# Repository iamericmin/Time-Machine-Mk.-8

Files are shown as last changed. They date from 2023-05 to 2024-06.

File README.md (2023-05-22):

# Time Machine Mk. 8
Home of the Time Machine Mk. 8, a digital watch inspired by F1 and Neon Genesis Evangelion.

# Repo Map
TM8-firmware:
<<<<<<< HEAD
	- scratchpad: Arduino sketches for quick testing
	- TM8: PlatfomIO project directory.

TM8-hardware:
	- root: Contains current TM8 production files and top/bottom PNG renders
	- Prototypes: previous versions of TM8. Current versions in root directory.
	- Technical Drawings: PDFs of TM8 exported from Eagle
	- Cutting Board: old TM8 versions that were tossed away
	- dock: TM8 dock design files
	- Side projects: smaller side projects to go along with TM8.
=======
  1. scratchpad: Arduino sketches for quick testing
  2. TM8: PlatfomIO project directory.

TM8-hardware:
  1. root: Contains current TM8 production files and top/bottom PNG renders
  2. Prototypes: previous versions of TM8. Current versions in root directory.
  3. Technical Drawings: PDFs of TM8 exported from Eagle
  4. Cutting Board: old TM8 versions that were tossed away
  5. dock: TM8 dock design files
  6. Side projects: smaller side projects to go along with TM8.
>>>>>>> 88637fd49bccefb3e3033934de54475b4d8ace5f

Documentation directory will be created soon!

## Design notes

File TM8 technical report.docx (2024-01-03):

TIME MACHINE MK. 8

Technical Report

Chief Technical Officer Eric Min

SPECS:

  1. CPU: ATSAMD21G18A-AU ARM CORTEX M0+ @ 48MHz
  2. DIMENSIONS: 41.91mm x 41.91mm x 8.6mm
  3. I/O: 4 momentary switches, central rotary knob, twin LCD displays, 5 auxiliary front LEDs, twin RGB backlights, twin floodlights, piezo buzzer, USB port
  4. COLORWAY: Electroless nickel-immersion gold on red soldermask, “Thunder and Lightning”
  5. POWER: LIR2032 40mAh Lithium Polymer coin cell battery w/ charging over micro-USB
  6. SENSORS: BME680 Temperature/Humidity/Barometer/Altitude sensor, LIS3DH 3-axis accelerometer, MAX17048 battery fuel gauge
  7. FIRMWARE: written in C/C++ with PlatformIO’s Arduino Atmel-SAM framework

DESIGN

Overall design: Chief Design Engineer Eric Min

Designing the Time Machine Mk. 8 to be both beautiful and practical required very deep thinking. Our team had to straddle a fine line between striking design and everyday useability. Finding the convergence point of those two crucial characteristics was extremely difficult, but our design team fulfilled every goal we initially set out to do, and some more. The Time Machine Mk. 8 retains the instantly recognizable silhouette of its predecessors, but brings forth a whole slew of incredibly advanced features, all in a smaller package.

The Time Machine Mk. 8 is a huge step forward in terms of technological prowess and design goals. While previous generation Time Machines were very simple watches cobbled together without much thought, TM8 is our first product made with focus on a singular goal: maximum performance and style at the lowest possible power consumption. We wanted to retain the iconic design language of our previous Time Machines, while still incorporating the numerous new features of our new model. This proved much harder than we initially thought, but at the end, it couldn’t have turned out any better.

Ever since the Mk. 2, the Time Machines’ muscular and angular lines have been an integral part of its design language. With the Mk. 8, we reprofiled the “fender flares” to be better proportioned with the rest of the chassis, as well as mimic the look of the muscular bulged fenders of classic 80’s cars, such as the Fiat 131 Abarth or the Lamborghini Countach. More importantly, while the fender flares were simply a design element in previous time machines, it actually serves a functional purpose in the Mk. 8 since it provides valuable PCB area for the numerous new functions we added to the watch. Without them, we wouldn’t have been able to fit in all the features we had planned.

Ergonomics & Front Fascia design: Systems Designer Eric Min

The front fascia is a radical departure from the usual two-digit, three-button layout familiar in previous generations. Our team decided two digits was not going to be enough for TM8, since with its new telemetry sensors, the watch would have to relay more information than just time. It took a painfully long time to look for and decide on the right display. Near the end, our team narrowed it down to a four digit, seven segment display as it fit nicely with our retro-futuristic design. While an OLED display was significantly cheaper and had better graphics, the design team concluded it would look awkward with the rest of the watch, and was therefore sacked. We trusted our software team to squeeze the most out of the LCD’s limitations. After all, working with and around limitations is what we do best. Furthermore, not only would the LCD provide significantly lower power consumption, the design team also fell in love with the fact that when two of those LCDs were put side by side, it resembled something like a Formula 1 steering wheel. Which brings us to the buttons…

While Min Works solely works in the electrical domain, we have always been fascinated by all things mechanical, automobiles being one of them. One day, we came up with the novel idea of making the Time Machine Mk. 8’s front fascia resemble an F1 steering wheel. Skeptical at first, our design team quickly landed on a design that made excellent use of available space without compromising usability and design. The final design has a central rotary “cooker” knob, flanked by two tactile momentary switches on each side, with twin LCDs on top to make an 8-digit display. The five auxiliary LEDs were carried over directly from previous generations, placed in parallel with the fender flares like the Mk. 4. The result is an extremely unique design that satisfies all our target design goals without compromising practicality.

The central cooker knob provides a new method of user input, not too different from the digital crown in an Apple Watch. The 16-step cooker knob provides a satisfying click with each actuation, and we think the engraved hexadecimal codes provide extra design flair to the watch. Unlike a conventional rotary switch, the one on TM8 outputs in 4-bit parallel BCD, meaning our software doesn’t have to track and store actuator position, making firmware development significantly easier.

The flanked buttons were angled to provide a more aggressive look, but also to provide enough distance apart so that a finger could feel and press the buttons without the user having to look at the watch. This would be useful in situations such as lap timing, when the user would have the watch strapped to a steering wheel. Being able to “touch-type” would be crucial during such instances.

Livery & Aesthetics: Graphics Designer Eric Min

The design team was at first a bit afraid that our design goals of incorporating twin LCDs and a cluster of buttons and switches would limit PCB space for a livery, but it turned out we just weren’t being creative enough. Our livery design took more development time than we would like to admit, but the end results are simply phenomenal. Our team dubbed the TM8’s design, “Thunder and Lighting.”

On the left, we have exposed copper artwork of a thunderbolt, painstakingly designed to fit in well with the overarching aesthetic of the watch. It took us quite a long time to land on a design that was visually striking but not overly busy.

On the right, our circuit design engineers worked in tandem with the design team and took some liberty to route copper traces that would work both functionally and aesthetically. When PCB routing was finalized, the design team overlayed select copper traces with white silkscreen to make a “lightning bolt” of signals. Like “thunder”, “lightning” also took quite a bit of time in coming up with the overall design, selecting which traces to paint white, and which to keep red. Accompanying “lightning” is a stylized Min Works logo, along with a small “TM-008 PROTOTYPE” script nestled into the upper-right corner, both in exposed copper.

Often, the design team was split into opinions of how our livery looked; some thought it was too busy, while others thought it was a bit subtle. Much debate and discussion went on between these parties, but we eventually reached a nice middle ground that gave just enough visual pop without being too loud.

For the lugs, we took inspiration from Unit 02 from Neon Genesis Evangelion. With Red being our representative color, we found Eva Unit 02 to be the perfect design inspiration, which we took in the form of exposed copper scripts on the lugs. On the front, they designate the model number and on the back, we have lyrics for Frank Sinatra’s Fly Me to the Moon, a tribute to Min Works’s founder Jihong Min, who is an Evangelion afficionado. Additionally, the lugs were reduced from 22mm to 18mm, and the lug hole corners were chamfered in for better structural rigidity, as acute angles are more prone to mechanical stress than obtuse angles.

HARDWARE DESIGN

Overall hardware: Chief Technical Officer Eric Min

Designing any embedded system is no easy task, but it was especially hard for Time Machine Mk. 8, where our primary goal was to cram as many features as possible into the smallest amount of space while using the least amount of power. Before anything else, our hardware design team came up with a list of hard rules that would set the limitations for designing Time Machine Mk. 8:

1. The watch must be smaller than any previous Time Machine, without any compromise on previous features.
2. PCB should be 2 layers with minimum trace width at 8 mils, and minimum via diameter at 0.3mm
3. The battery must be rechargeable, and charging should be fully contained on the PCB without the need for any external circuitry.
4. The battery must be a 40mAh LIR2032 Li-Po coin cell, held directly onto the PCB for minimum thickness.
5. The microcontroller must deliver high performance with low power, with an RTC, native USB, and at least two I2C buses required.
6. The watch should do more than simply measure and tell time.
7. Only the LCDs, LEDs, and buttons are allowed on the front side. All other components should be away from view at the back, or under the LCD glass.

Our engineers followed this set of rules throughout the entire design process, and while we were temped to break some of them, especially rules 1 and 2, we eventually developed TM8 as a fully self-contained package satisfying all our design goals.

Microcontroller: Embedded Systems Engineer Eric Min

With so many incredible microcontrollers available for dirt cheap on today’s market, it was pretty tough deciding on a micro to power our latest watch. Our team was focused primarily on ultra low power performance, and we flipped through hundreds of datasheets and manufacturer reference pages while narrowing down our choices. We decided early on to choose a 32-bit processor, as the current crop of ARM Cortex microcontrollers offered excellent computational performance while also killing the low-power game. Our requirement of a real-time clock and two I2C buses were also nowhere to be found on any 8-bit micro. After some research, our team whittled our list down to five choices: Espressif’s ESP32, Nordic’s NRF52832, the Raspberry Pi Foundation’s RP2040, Microchip’s ATSAMD21G18, or Silab’s EFM32 Zero Gecko, in descending order of performance.

We finally decided on the ATSAMD21G18 since we believed it gave the best performance and peripheral set with uncompromising low-power consumption, along with an incredible community of fellow engineers to rely on with any technical issues. The chip’s high popularity also meant we had no shortage of excellent reference designs to follow, such as Adafruit’s Feather M0 or Sparkfun’s 9DoF Razor IMU. We especially found the SAMD21’s SERCOMs extra appealing as it gave us incredible flexibility when routing our PCB. We didn’t have to worry as much about parts placement as we could simply assign I2C buses to pins best placed for the job. While the ESP32 and NRF52832’s wireless peripherals were pretty enticing, the team concluded that high power consumption during moments of wireless activity defeated the watch’s purpose. With a 40mAh battery, any sort of wireless radio would drain the battery pretty fast. Plus, their lack of native USB meant an automatic no from the get-go.

The SAMD21’s real-time clock (RTC) was also incredibly handy, as it allowed us to keep track of time without any CPU overhead and minimal power consumption.

Sensors: Telemetry Engineer Eric Min

As stated in the requirements above, we wanted Time Machine Mk. 8 to be more than just a time-telling device. Unlike previous versions, which didn’t do more than tell the time, the Mk. 8 is a genuine precision tool capable of measuring, recording, and analyzing various telemetry data. With so many incredible sensors available off-the-shelf, we took our time deciding which sensors to use, before landing on three: Analog Devices’ MAX17048 fuel gauge, Bosch Sensortec’s BME680 environmental sensor, and ST Micro’s LIS3DH 3-axis accelerometer. The first one was a no-brainer: while we considered implementing a rudimentary battery gauge using an ADC pin, we figured an external sensor’s higher accuracy and simple I2C communication was worth it. The BME680 offered a thermometer, humidity sensor, and barometer, while still boasting incredibly low power consumption, giving us an excellent low-power, high-performance sensor package. While we wanted to use Invensense’s ICM20948 9-DoF IMU, we couldn’t find any PCB space to incorporate the sensor’s required 1.8v power regulation circuitry. We figured the next best option would be a 3-axis accelerometer, and the LIS3DH offers great performance for low power. These sensors, coupled with the lean and fast ATSAMD21G18 processor, allow for incredibly fast telemetry acquisition and computation in real time.

Battery: Low-Power design engineer Eric Min

Pretty much everything in TM8’s design process revolved around the battery. We decided early on to incorporate a coin cell battery directly on the watch, just like previous Time Machines, to make it as thin as possible. While this would hurt its battery life, slick aesthetics was also one of our main design goals, and we believed in our low-power design team to work their magic to squeeze the most battery life out of the SAMD21 as possible. We decided to go for a rechargeable battery to mitigate this loss. Luckily, there was an off-the-shelf rechargeable alternative to CR2032 cells, the LIR2032. Being only 40mAh, it’s less than five times smaller than a CR2032, but its familiar 20mm diameter, 3.2mm thickness footprint made PCB design much easier than it would have been with other conventional lithium-polymer batteries.

With no prior experience with rechargeable batteries, we were taking a huge risk here with TM8. We studied numerous reference designs on the internet, and found some solid ones with good documentation that allowed us to make our own reliable power supply circuit. Using a 3.3v LDO voltage regulator, a Li-Po battery charger IC, and a P-channel MOSFET, our team created a rock-solid power supply with seamless switching between the battery and external USB power. Coupled with the MAX17048 fuel gauge IC, TM8 is well optimized for low-power operation.

PCB Design: PCB designer Eric Min

With the battery taking over a quarter of available space on the back of the watch, PCB space was incredibly tight, and our team worked for months optimizing the routing to find space. We are happy to report we’ve successfully implemented all our design goals within our target spec: 2 layers with traces no thicker than 8 mils. Our target spec was chosen so to minimize cost, as any tighter tolerances would’ve dramatically increased manufacturing costs. At one point we even had an IR receiver on the watch, but we removed it after a team meeting concluded it was too niche to be a legitimately useful feature. Instead, we replaced it with test pads for easier hardware debugging, should the need arise. Even without an IR receiver, TM8 is still the most complex, dense circuit we’ve ever designed. In fact, you can see components forming an arc right above where the battery sits, giving it just enough clearance to fit on the watch. Every nook and cranny was utilized, and we left no space on the watch unoccupied.

To route such a dense PCB, our team used 0402 size parts for the first time ever and reduced via size to 0.3mm. We also used SMD packages such as LGA and QFN for the first time. Using such footprints dramatically increased available board space. Time Machine Mk. 8 gave us numerous opportunities to try out new technologies, giving us valuable experience to build upon them in future projects.

While the front side wasn’t as

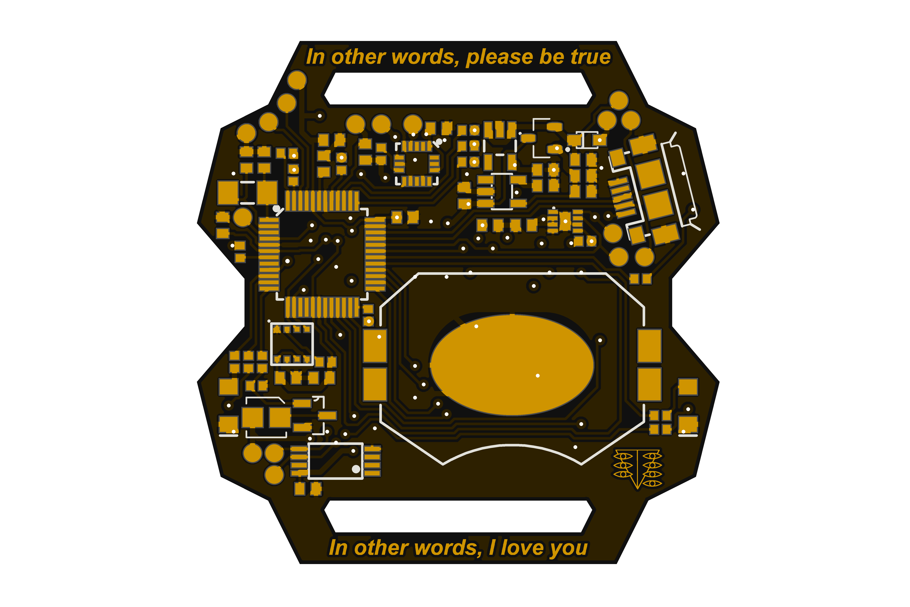
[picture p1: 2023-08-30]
TM8-hardware/tm8_bottom.png

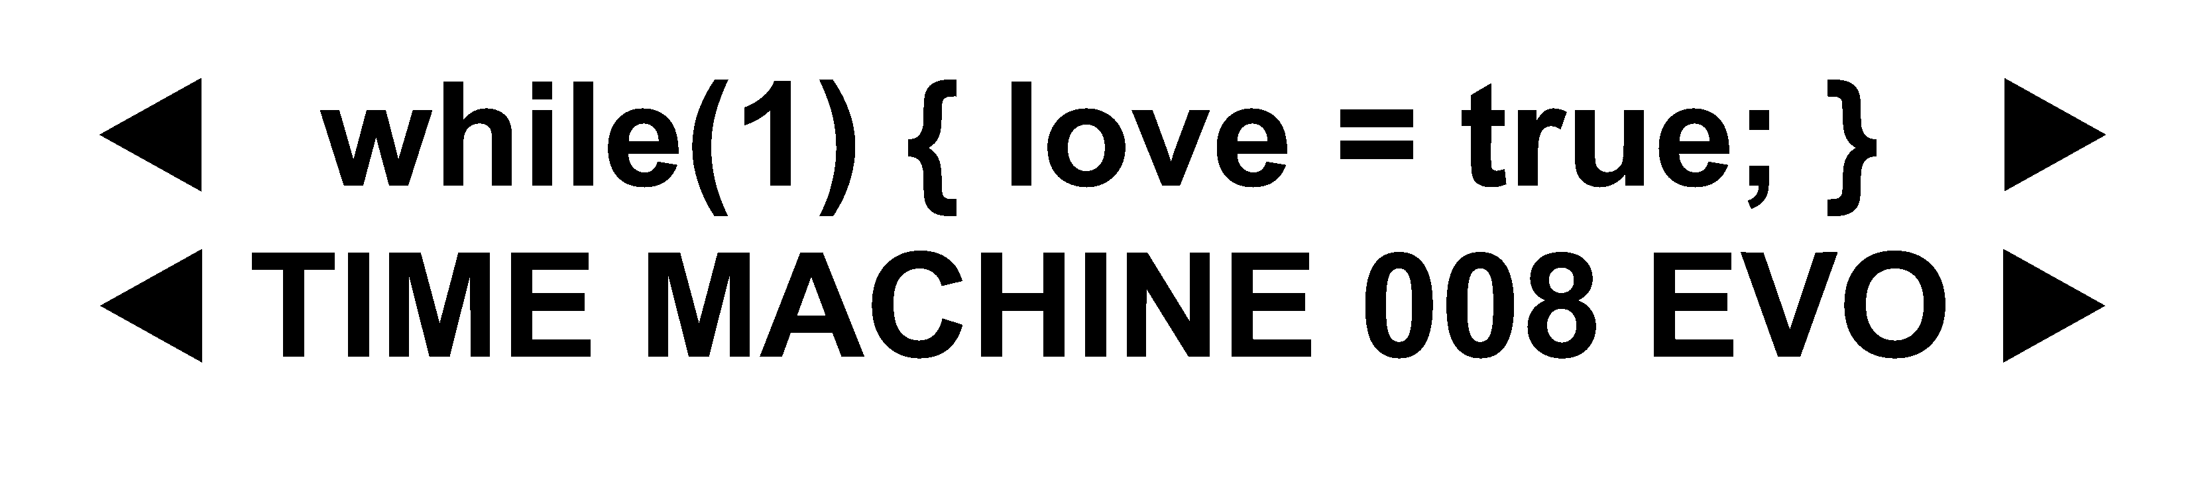
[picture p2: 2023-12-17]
TM8-hardware/resources/lug text.bmp

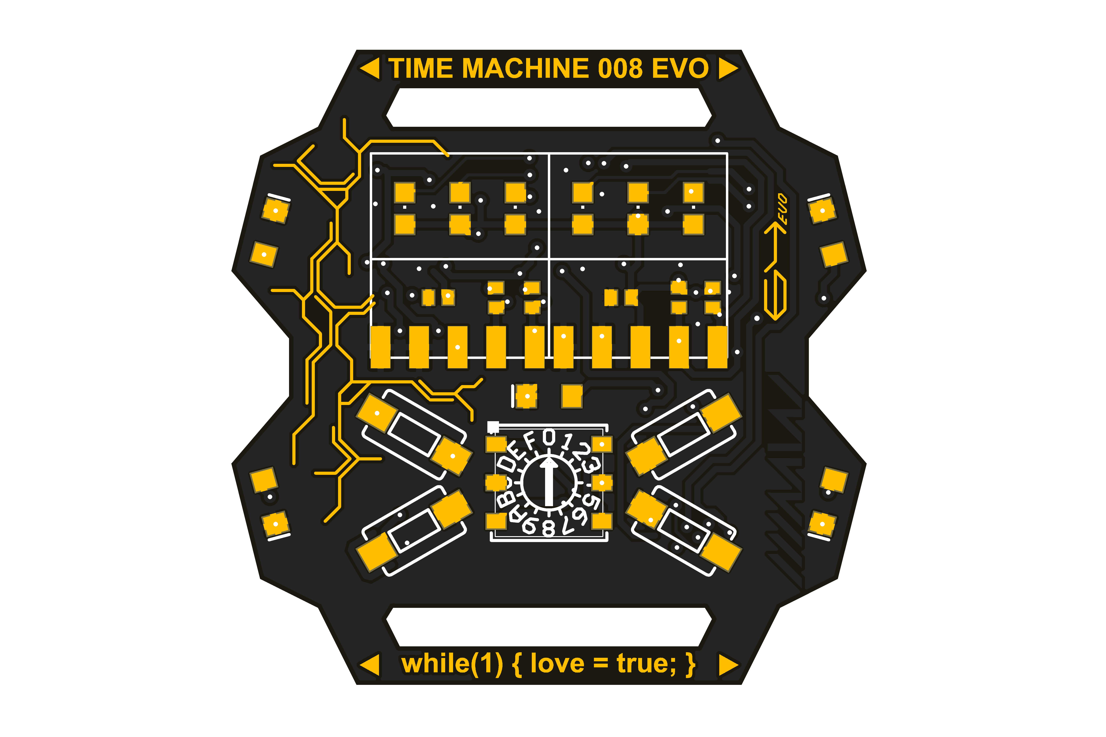
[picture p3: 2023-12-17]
TM8-hardware/TM8 Evo Dad.png

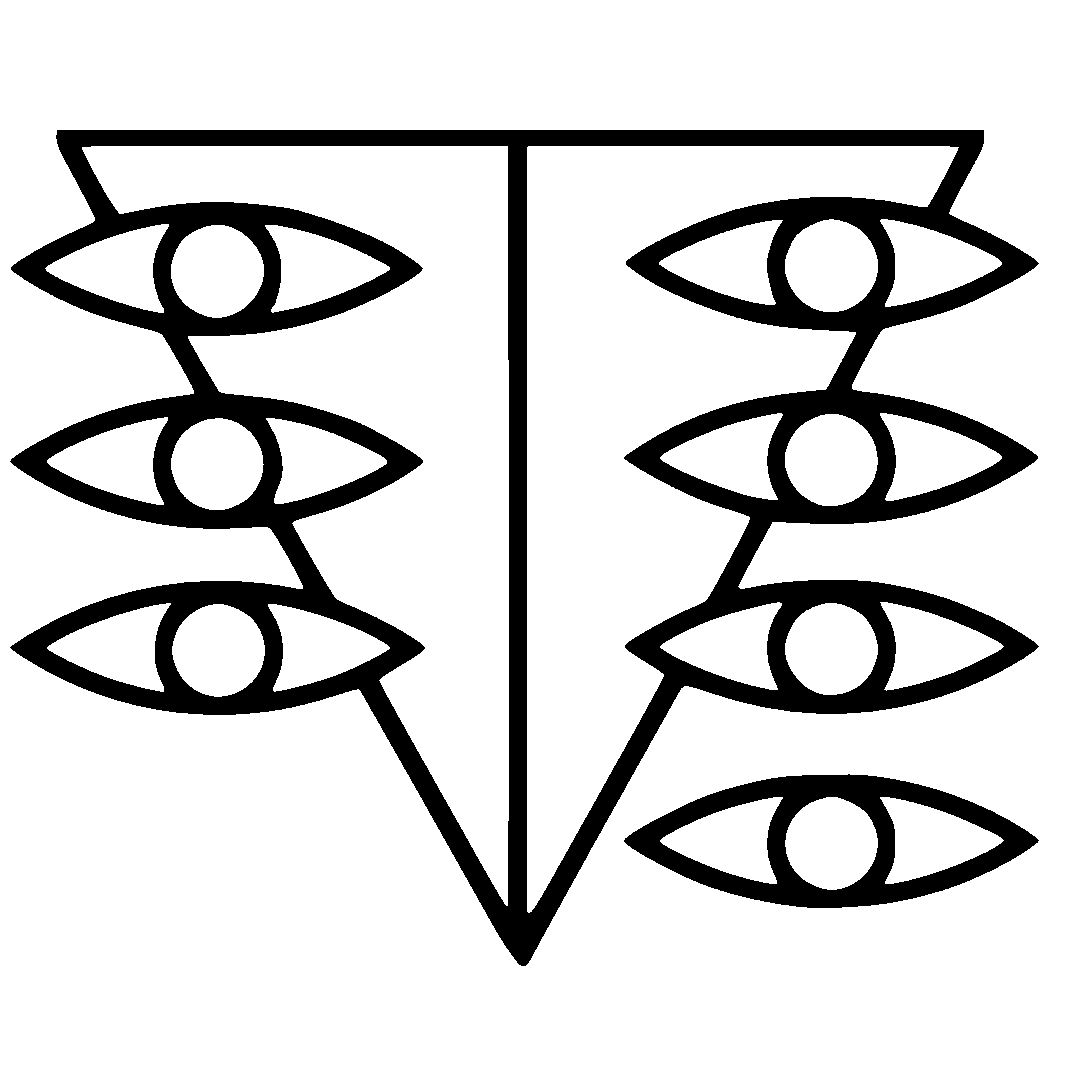
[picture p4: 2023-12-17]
TM8-hardware/resources/seele.bmp

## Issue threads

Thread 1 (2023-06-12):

Idea

SpeedGP, 2023-06-12:
Hey, sorry, I'm awful with Github stuff, but I was curious if you'd be interested in some sort of trade. I have a laser cutter and would like to make a protective plate or shell for this watch. Would you consider sending me one (I'm happy to solder my own if you wanted to send unsoldered components) and I could make a few different shell designs and send them to you.

Awesome work, keep it up!

James

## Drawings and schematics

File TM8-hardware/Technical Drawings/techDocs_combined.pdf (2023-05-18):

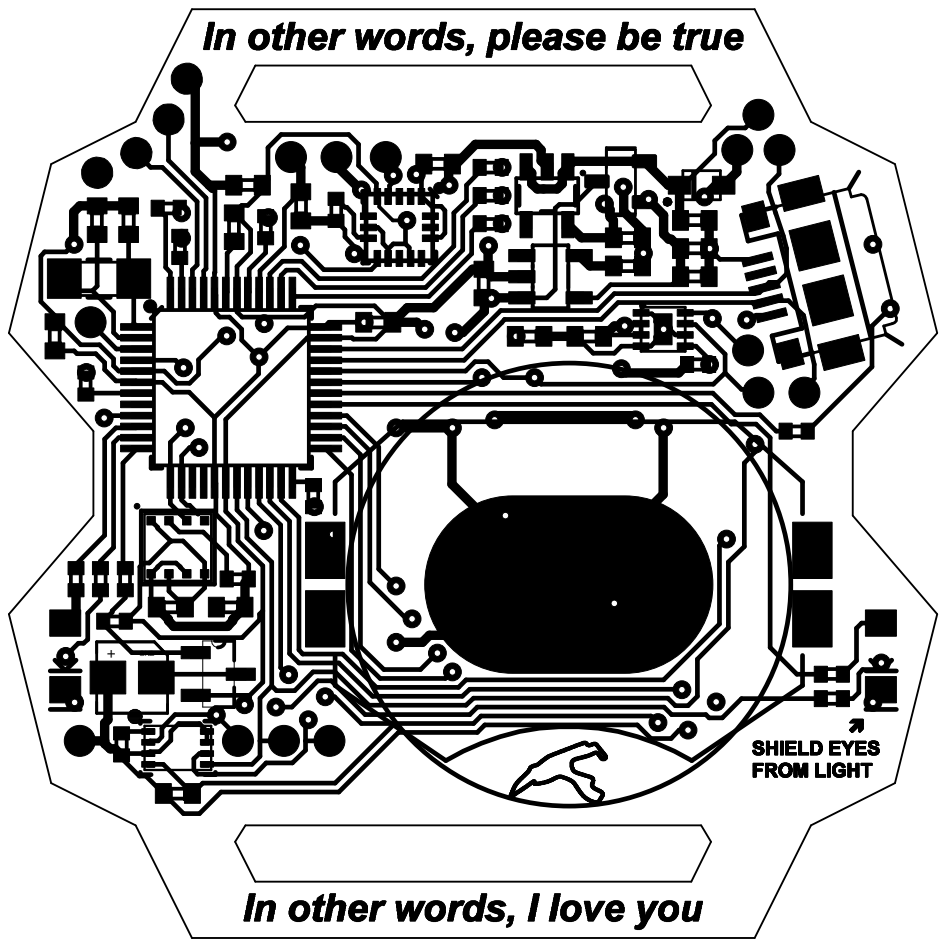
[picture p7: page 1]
GND

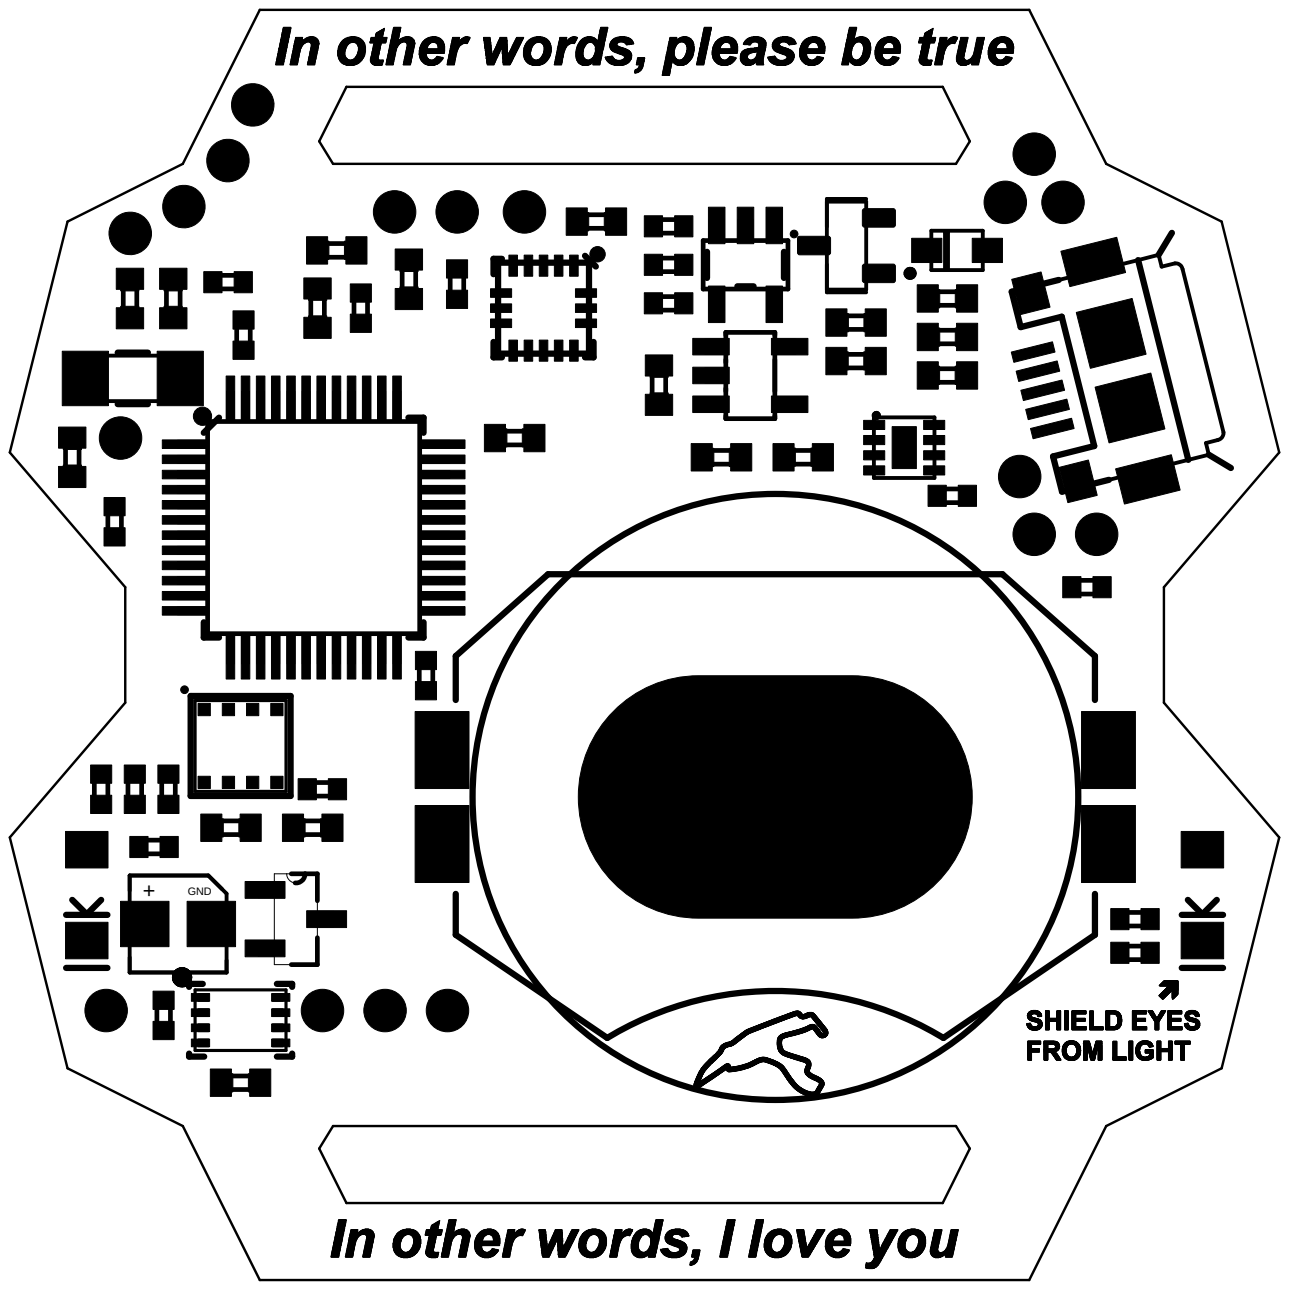
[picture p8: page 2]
GND

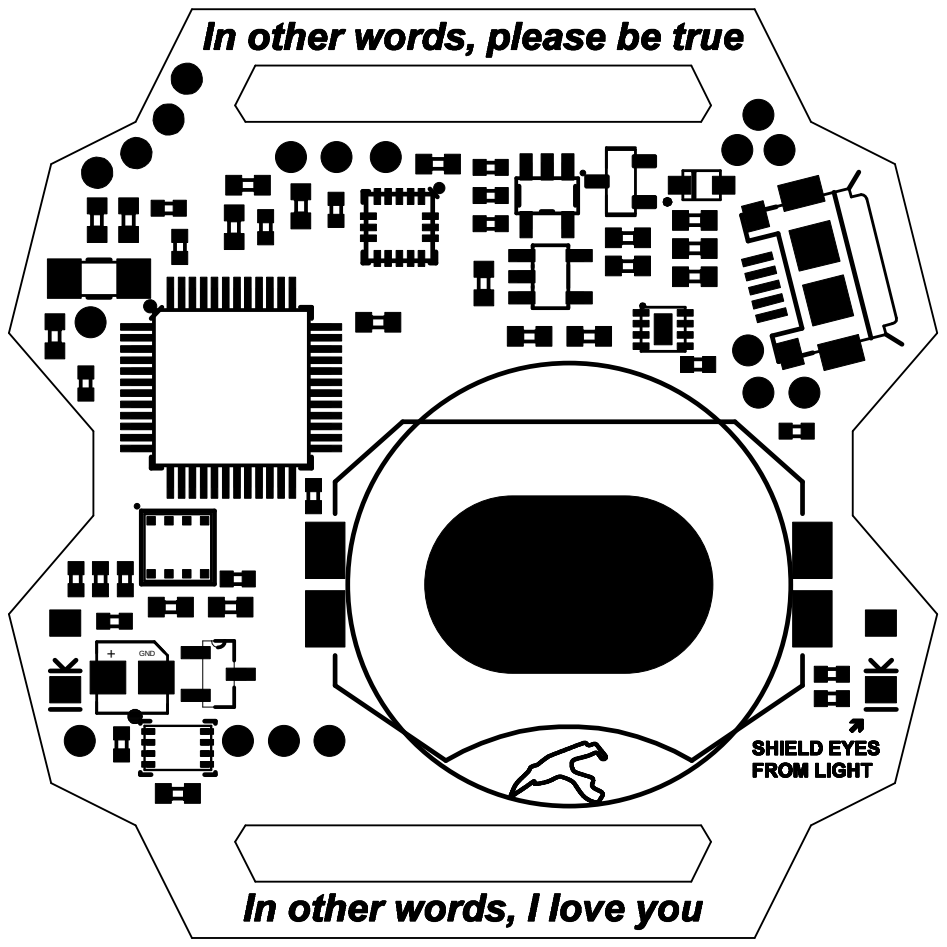
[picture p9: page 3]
GND

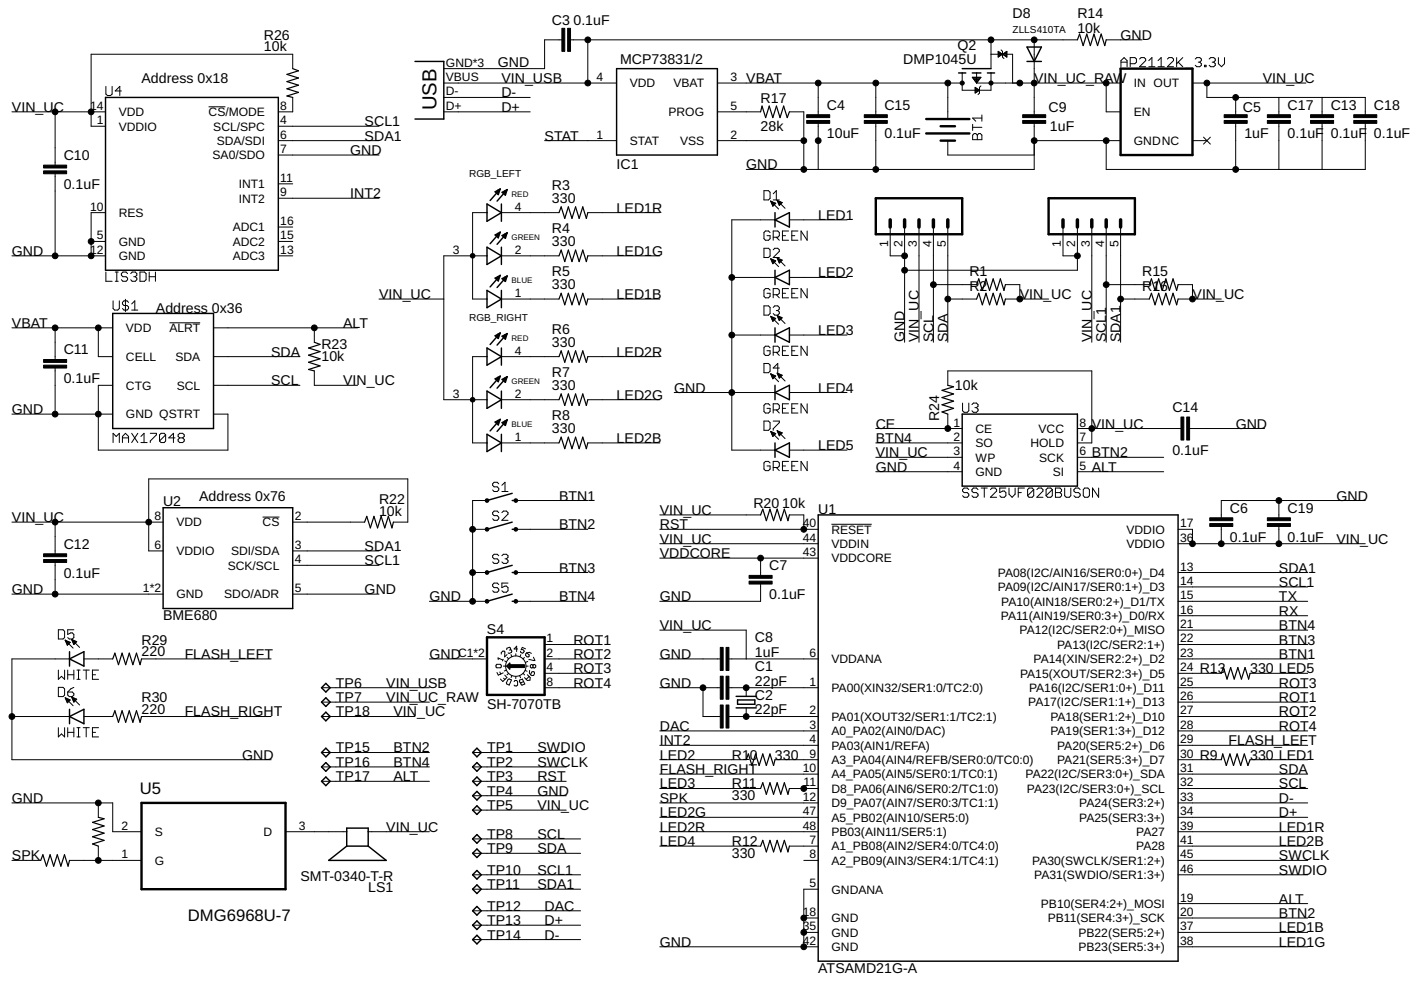
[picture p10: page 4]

GND QSTRT SCL SDA

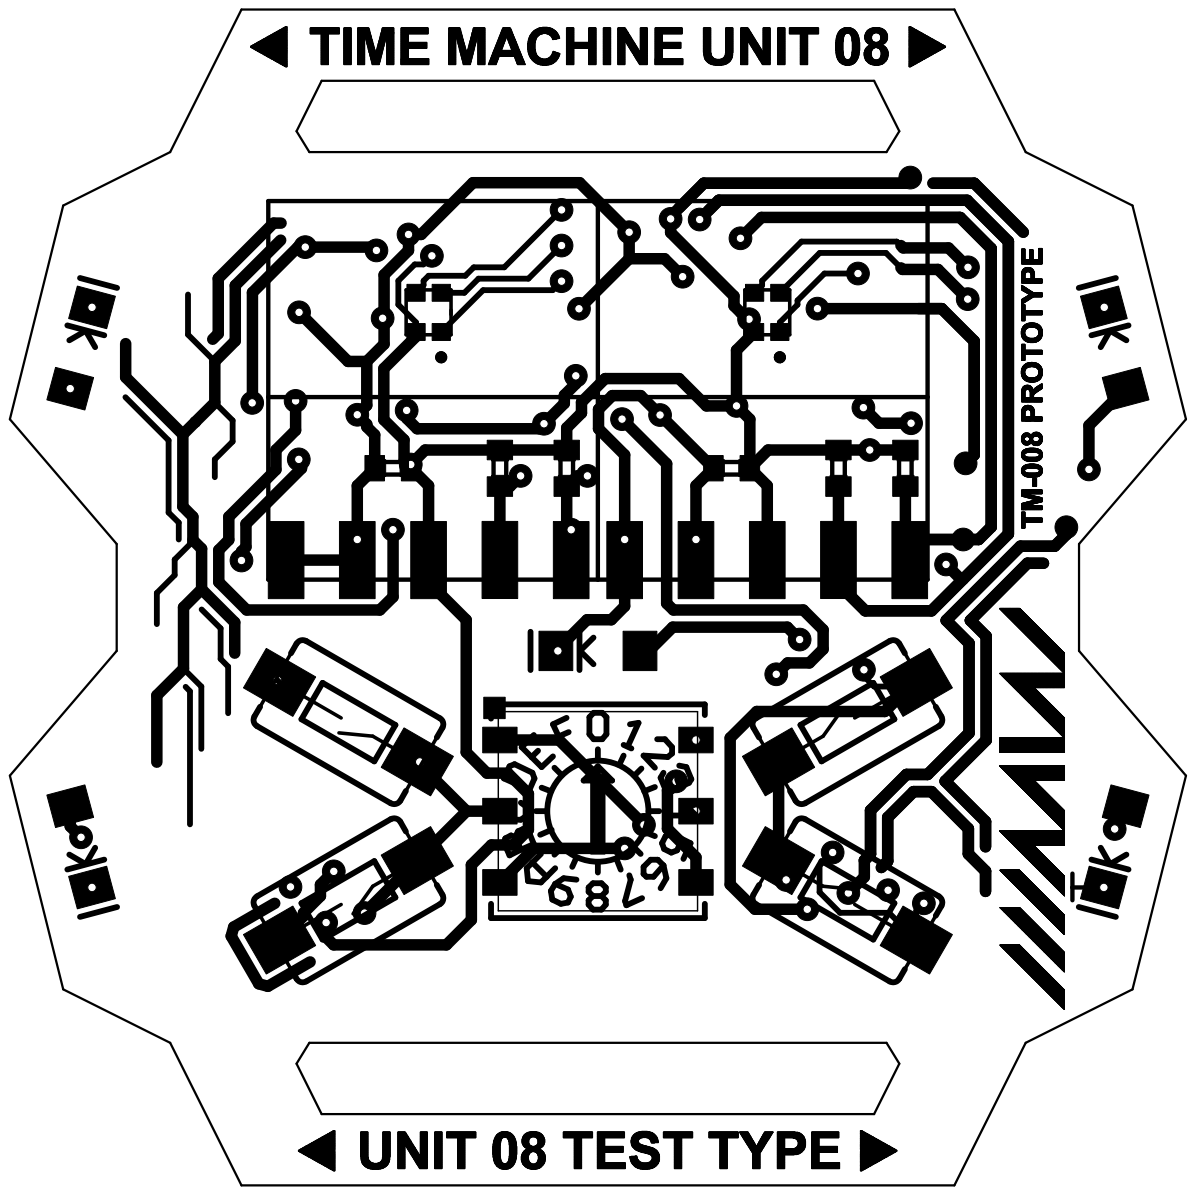
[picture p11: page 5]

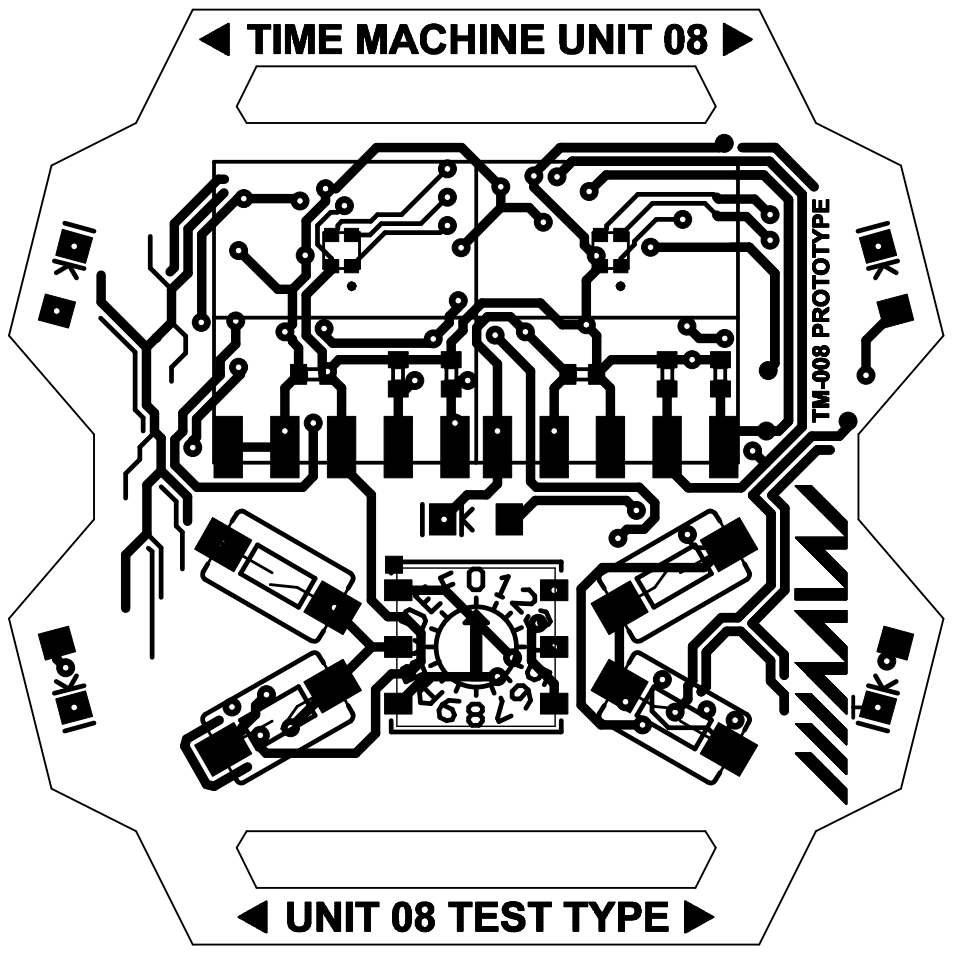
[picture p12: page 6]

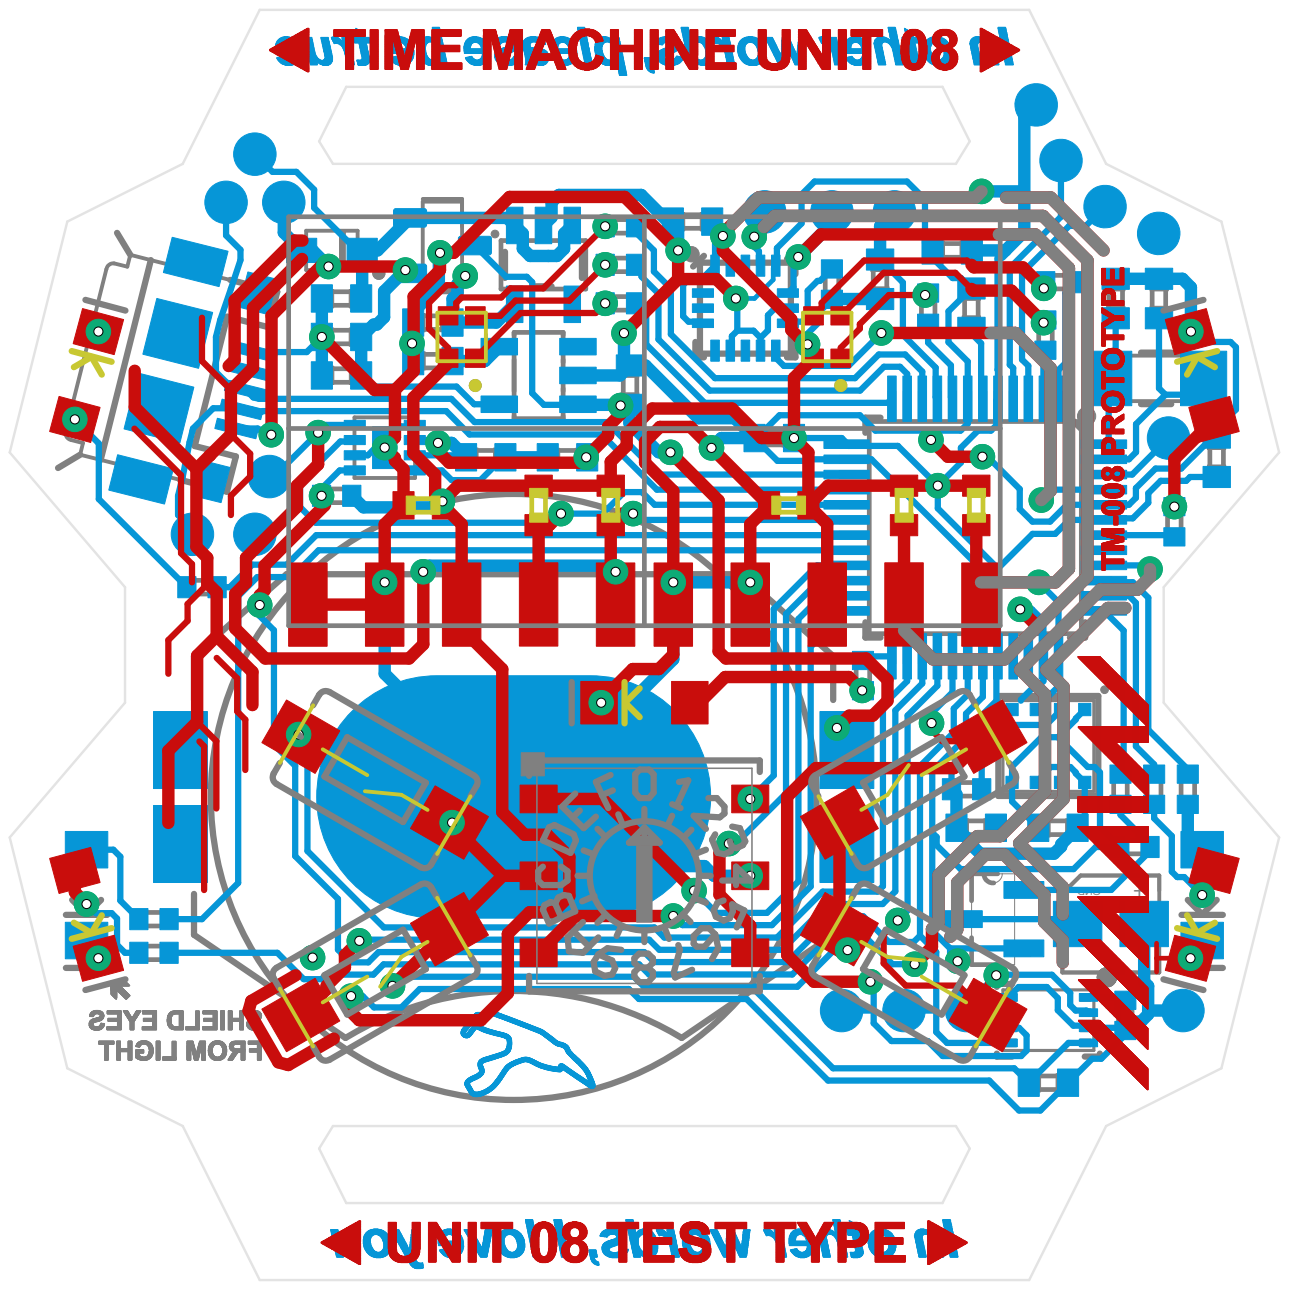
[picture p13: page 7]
DNG +

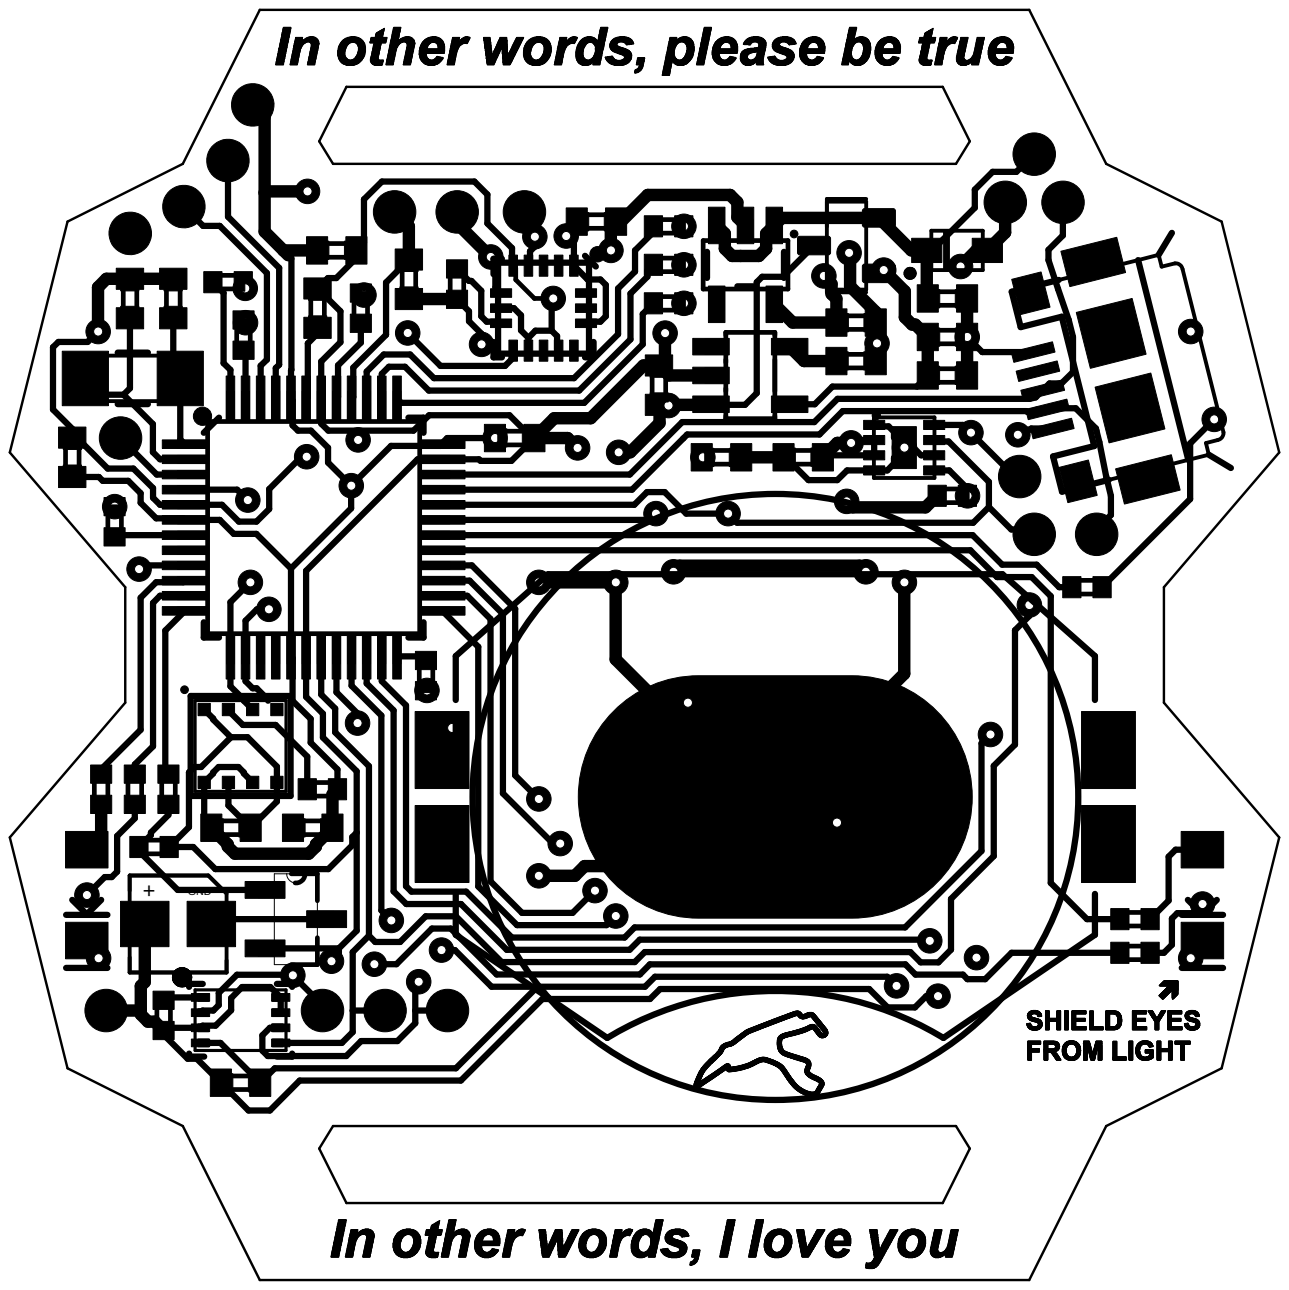
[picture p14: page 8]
GND

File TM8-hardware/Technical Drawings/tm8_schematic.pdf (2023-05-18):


GND QSTRT SCL SDA








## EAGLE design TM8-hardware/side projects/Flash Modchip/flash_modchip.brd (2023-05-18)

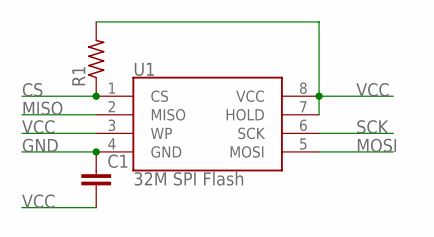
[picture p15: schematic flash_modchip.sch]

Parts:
C1: C-EUC0402; C0402
R1: R-US_R0402; R0402
U1: 32M SPI Flash; SO08

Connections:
CS: R1.1, U1.1 (CS)
GND: C1.1, U1.4 (GND)
MISO: U1.2 (MISO)
MOSI: U1.5 (MOSI)
SCK: U1.6 (SCK)
VCC: C1.2, R1.2, U1.3 (WP), U1.7 (HOLD), U1.8 (VCC)

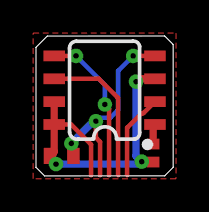
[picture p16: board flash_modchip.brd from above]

Board: 2 copper layers, 7.6 x 7.8 mm, 3 parts (0 on the bottom side), 3 nets.

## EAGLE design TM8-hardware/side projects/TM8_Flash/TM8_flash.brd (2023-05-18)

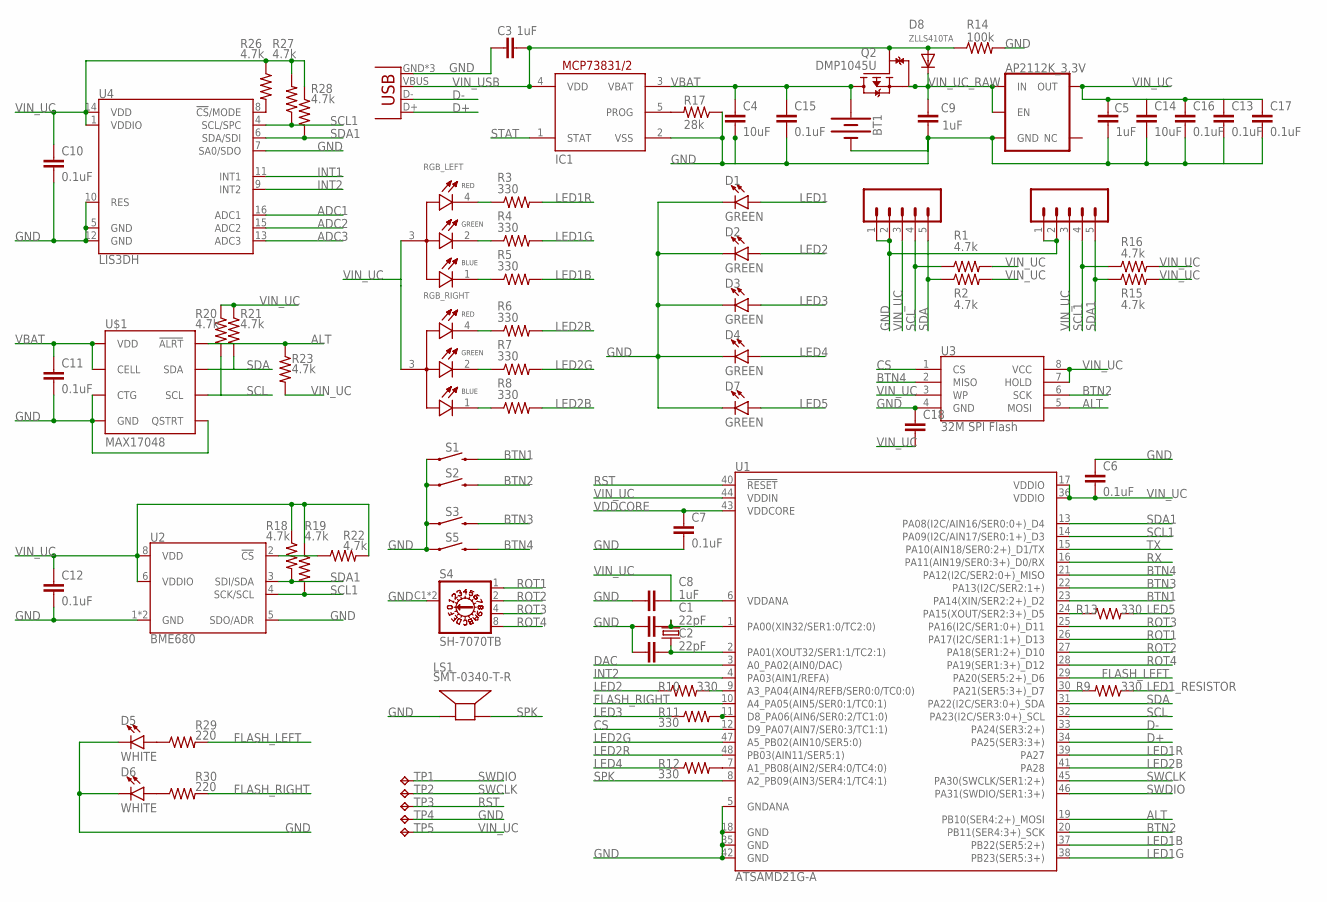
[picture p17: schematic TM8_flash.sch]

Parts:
AP2112K_3.3V: 3.3V; SOT23-5
BT1: BATTERY-20MM_SMD_4LEGS_OVERPASTE_INNER; BATTCON_20MM_4LEGS_OVERPASTE_INNER
C1, C2: 22pF; C0402
C3, C5, C8, C9: 1uF; C0402
C4, C14: 10uF; C0402
C6, C7, C10, C11, C12, C13, C15, C16, C17: 0.1uF; C0402
C18: C-EUC0402; C0402
D1, D2, D3, D4, D7: GREEN; LED-1206
D5, D6: WHITE; LED-1206
D8: ZLLS410TA; SOD-323F
IC1: MCP73831/OT; SOT23-5L
JP2: USB-MICROB
LCD1, LCD2: CONN_05VERT_FEMALE_HEADER; 1X05_SMD_VERTICAL_COMBO
LS1: SMT-0340-T-R; XDCR_SMT-0340-T-R
Q2: DMP1045U; SOT91P240X110-3N
R1, R2, R15, R16, R18, R19, R20, R21, R22, R23, R26, R27, R28: 4.7k; R0402
R3, R4, R5, R6, R7, R8, R9, R10, R11, R12, R13: 330; R0402
R14: 100k; R0402
R17: 28k; R0402
R29, R30: 220; R0402
RGB_LEFT: EAST1616RGBA3; LED_EAST1616RGBA3
RGB_RIGHT: EAST1616RGBA3; LED_EAST1616RGBA3
S1, S2, S3, S5: MOMENTARY-SWITCH-SPST-SMD-6.0X3.5MM; TACTILE_SWITCH_SMD_6.0X3.5MM
S4: SH-7070TB; SH-7070B
TP1, TP2, TP4, TP5: TPTP14R; TP14R
TP3: TPTP11R; TP11R
U1: ATSAMD21G-A; TQFP-48
U2: BME680; LGA3.0X3.0
U3: 32M SPI Flash; SO08
U4: LIS3DH; LGA-16-3X3
U$1: MAX17048; DFN-8
Y1: 32.768kHz; CRYSTAL-SMD-3.2X1.5MM

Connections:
ADC1: U4.16 (ADC1)
ADC2: U4.15 (ADC2)
ADC3: U4.13 (ADC3)
ALT: R23.1, U1.19 (PB10(SER4:2+)_MOSI), U3.5 (MOSI), U$1.P$5 (!ALRT)
BTN1: S1.2, U1.23 (PA14(XIN/SER2:2+)_D2)
BTN2: S2.2, U1.20 (PB11(SER4:3+)_SCK), U3.6 (SCK)
BTN3: S3.2, U1.22 (PA13(I2C/SER2:1+))
BTN4: S5.2, U1.21 (PA12(I2C/SER2:0+)_MISO), U3.2 (MISO)
CS: U1.12 (D9_PA07(AIN7/SER0:3/TC1:1)), U3.1 (CS)
D+: JP2.D+, U1.34 (PA25(SER3:3+))
D-: JP2.D-, U1.33 (PA24(SER3:2+))
DAC: U1.3 (A0_PA02(AIN0/DAC))
FLASH_LEFT: R29.2, U1.29 (PA20(SER5:2+)_D6)
FLASH_RIGHT: R30.2, U1.10 (A4_PA05(AIN5/SER0:1/TC0:1))
GND: AP2112K_3.3V.2 (GND), BT1.2 (-), C1.1, C2.1, C3.1, C4.2, C5.2, C6.1, C7.2, C8.1, C9.2, C10.2, C11.2, C12.2, C13.2, C14.2, C15.2, C16.2, C17.2, C18.1, D1.C, D2.C, D3.C, D4.C, D5.C, D6.C, D7.C, IC1.2 (VSS), JP2.GND, JP2.MT1 (GND), JP2.MT2 (GND), LCD1.1, LCD1.2, LCD2.1, LCD2.2, LS1.P, R14.2, R17.1, S1.1, S2.1, S3.1, S4.C1 (C), S4.C2 (C), S5.1, TP4.TP, U1.5 (GNDANA), U1.18 (GND), U1.35 (GND), U1.42 (GND), U2.1 (GND), U2.5 (SDO/ADR), U2.7 (GND), U3.4 (GND), U4.5 (GND), U4.7 (SA0/SDO), U4.10 (RES), U4.12 (GND), U$1.P$1 (CTG), U$1.P$4 (GND), U$1.P$6 (QSTRT), U$1.P$9 (GND)
INT1: U4.11 (INT1)
INT2: U1.4 (PA03(AIN1/REFA)), U4.9 (INT2)
LED1: D1.A
LED1B: R5.2, U1.37 (PB22(SER5:2+))
LED1G: R4.2, U1.38 (PB23(SER5:3+))
LED1R: R3.2, U1.39 (PA27)
LED1_RESISTOR: R9.1
LED2: D2.A, R10.1
LED2B: R8.2, U1.41 (PA28)
LED2G: R7.2, U1.47 (A5_PB02(AIN10/SER5:0))
LED2R: R6.2, U1.48 (PB03(AIN11/SER5:1))
LED3: D3.A, R11.1
LED4: D4.A, R12.1
LED5: D7.A, R13.2
unnamed: R12.2, U1.7 (A1_PB08(AIN2/SER4:0/TC4:0))
unnamed: R11.2, U1.11 (D8_PA06(AIN6/SER0:2/TC1:0))
unnamed: R9.2, U1.30 (PA21(SER5:3+)_D7)
unnamed: R10.2, U1.9 (A3_PA04(AIN4/REFB/SER0:0/TC0:0))
unnamed: R3.1, RGB_LEFT.4 (R_C)
unnamed: R4.1, RGB_LEFT.2 (G_C)
unnamed: R5.1, RGB_LEFT.1 (B_C)
unnamed: R6.1, RGB_RIGHT.4 (R_C)
unnamed: R7.1, RGB_RIGHT.2 (G_C)
unnamed: R8.1, RGB_RIGHT.1 (B_C)
unnamed: R13.1, U1.24 (PA15(XOUT/SER2:3+)_D5)
unnamed: IC1.5 (PROG), R17.2
unnamed: R22.1, U2.2 (!CS)
unnamed: D5.A, R29.1
unnamed: R26.2, U4.8 (!CS!/MODE)
unnamed: D6.A, R30.1
ROT1: S4.1, U1.26 (PA17(I2C/SER1:1+)_D13)
ROT2: S4.2, U1.27 (PA18(SER1:2+)_D10)
ROT3: S4.4, U1.25 (PA16(I2C/SER1:0+)_D11)
ROT4: S4.8, U1.28 (PA19(SER1:3+)_D12)
RST: TP3.TP, U1.40 (!RESET!)
RX: U1.16 (PA11(AIN19/SER0:3+)_D0/RX)
SCL: LCD1.4, R1.1, R20.2, U1.32 (PA23(I2C/SER3:0+)_SCL), U$1.P$7 (SCL)
SCL1: LCD2.4, R16.1, R19.2, R27.1, U1.14 (PA09(I2C/AIN17/SER0:1+)_D3), U2.4 (SCK/SCL), U4.4 (SCL/SPC)
SDA: LCD1.5, R2.1, R21.2, U1.31 (PA22(I2C/SER3:0+)_SDA), U$1.P$8 (SDA)
SDA1: LCD2.5, R15.1, R18.2, R28.2, U1.13 (PA08(I2C/AIN16/SER0:0+)_D4), U2.3 (SDI/SDA), U4.6 (SDA/SDI)
SPK: LS1.N, U1.8 (A2_PB09(AIN3/SER4:1/TC4:1))
STAT: IC1.1 (STAT)
SWCLK: TP2.TP, U1.45 (PA30(SWCLK/SER1:2+))
SWDIO: TP1.TP, U1.46 (PA31(SWDIO/SER1:3+))
TX: U1.15 (PA10(AIN18/SER0:2+)_D1/TX)
VBAT: BT1.1 (+), C4.1, C11.1, C15.1, IC1.3 (VBAT), Q2.3 (D), U$1.P$2 (CELL), U$1.P$3 (VDD)
VDDCORE: C7.1, U1.43 (VDDCORE)
VIN_UC: AP2112K_3.3V.5 (OUT), C5.1, C6.2, C8.2, C10.1, C12.1, C13.1, C14.1, C16.1, C17.1, C18.2, LCD1.3, LCD2.3, R1.2, R2.2, R15.2, R16.2, R18.1, R19.1, R20.1, R21.1, R22.2, R23.2, R26.1, R27.2, R28.1, RGB_LEFT.3 (A), RGB_RIGHT.3 (A), TP5.TP, U1.6 (VDDANA), U1.17 (VDDIO), U1.36 (VDDIO), U1.44 (VDDIN), U2.6 (VDDIO), U2.8 (VDD), U3.3 (WP), U3.7 (HOLD), U3.8 (VCC), U4.1 (VDDIO), U4.14 (VDD)
VIN_UC_RAW: AP2112K_3.3V.1 (IN), AP2112K_3.3V.3 (EN), C9.1, D8.C, Q2.2 (S)
VIN_USB: C3.2, D8.A, IC1.4 (VDD), JP2.VBUS, Q2.1 (G), R14.1
XIN32: C1.2, U1.1 (PA00(XIN32/SER1:0/TC2:0)), Y1.P$2 (2)
XOUT32: C2.2, U1.2 (PA01(XOUT32/SER1:1/TC2:1)), Y1.P$1 (1)

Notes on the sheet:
R14
R11
R12
R10
R13
R29
R30
R18
R19
R22
R23
R20
R21
R26
R27
R28

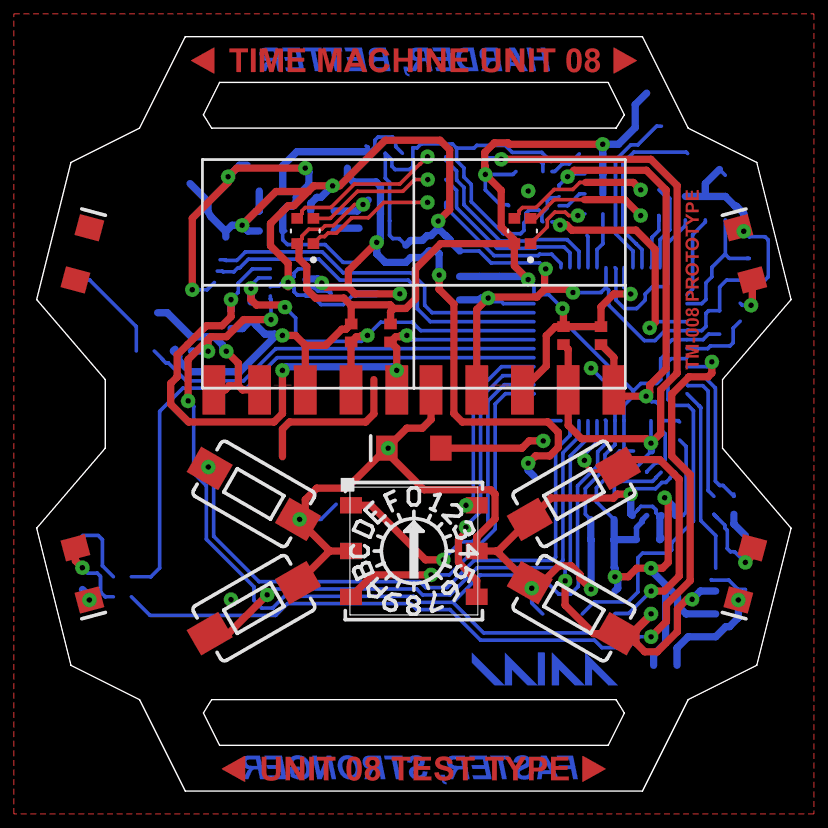
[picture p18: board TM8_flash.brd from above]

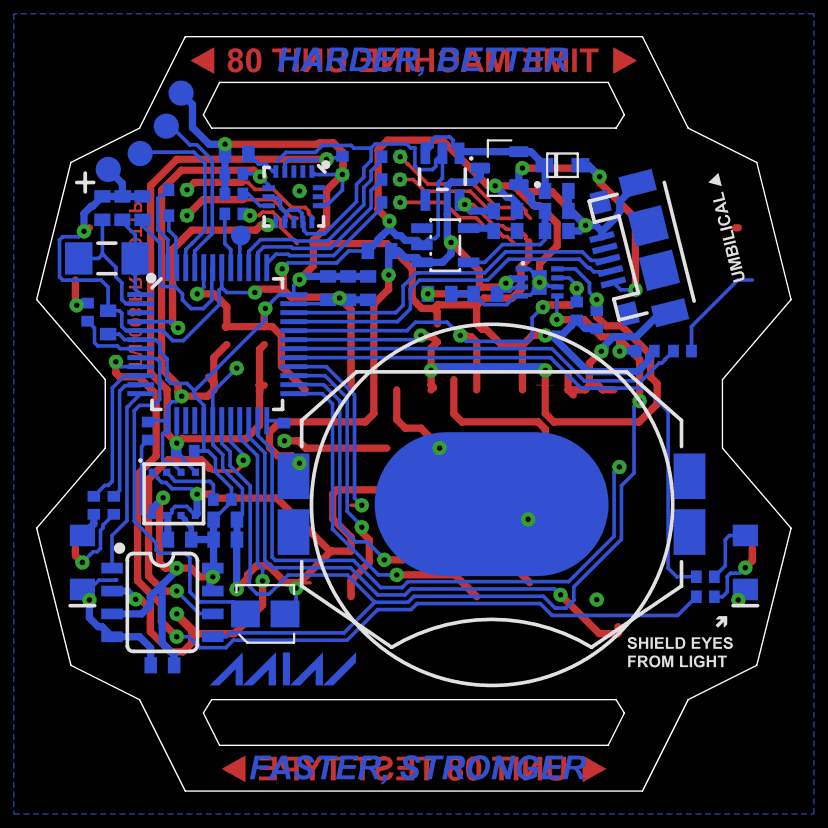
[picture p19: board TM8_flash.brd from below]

Board: 2 copper layers, 41.9 x 41.9 mm, 80 parts (62 on the bottom side), 57 nets.

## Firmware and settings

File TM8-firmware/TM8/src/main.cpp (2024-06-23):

/*
 _______             __  ___         __   _            __  _____       ___ 
/_  __(_)_ _  ___   /  |/  /__ _____/ /  (_)__  ___   /  |/  / /__    ( _ )
 / / / /  ' \/ -_) / /|_/ / _ `/ __/ _ \/ / _ \/ -_) / /|_/ /  '_/   / _  |
/_/ /_/_/_/_/\__/ /_/  /_/\_,_/\__/_//_/_/_//_/\__/ /_/  /_/_/\_(_)  \___/ 
TIME MACHINE MK. 8
MIN WORKS 2024
@designedbyericmin

GENERAL RULE OF THUMB:
Button 1: top left. scroll up
Button 2: buttom left. scroll down
Button 3: top right. confirm/enter
Button 4: top left. cancel/exit
*/

#include <Arduino.h>
#include <Wire.h>
#include "wiring_private.h" // pinPeripheral() function
#include <RTCZero.h>
#include <Adafruit_MAX1704X.h>
#include <ArduinoLowPower.h>
#include <SparkFunLIS3DH.h>
#include <bme68xLibrary.h>
#include <SparkFun_External_EEPROM.h>
#include <time.h>
#include <TM8_util.h>

#define INACTIVITY_TIMEOUT 2000 // inactivity threshold of 2 seconds
#define BUTTON_DELAY 100 // delay between button readings for scrolling, long press, etc.
#define LCD_ADDRESS 0x38
#define FUEL_ADDRESS 0x36
#define ACCEL_ADDRESS 0x18
#define BME_ADDRESS 0x76
#define ROM_ADDRESS 0x50

TwoWire wire1(&sercom2, 4, 3); // new Wire object to set up second I2C port on SERCOM 2
RTCZero rtc; // RTC object
Adafruit_MAX17048 fuel;
LIS3DH accel(I2C_MODE, 0x18);
Bme68x bme;
bme68xData BMEData;
ExternalEEPROM rom;
TM8_util TM8;

// I found after lots of trial and error this is the only way to get TM8 to read PA12
// without the whole thing freezing or acting up
// returns 0 when closed, 1 when open
#define readBtn1 (PORT->Group[0].IN.reg & (1 << 14))
#define readBtn2 (PORT->Group[0].IN.reg & (1 << 13))
#define readBtn3 (PORT->Group[1].IN.reg & (1 << 11))
#define readBtn4 (PORT->Group[0].IN.reg & (1 << 12))

const uint8_t btn1 = 2; // top left button
const uint8_t btn2 = 38; // bottom left button
const uint8_t btn3 = 24; // top right button
const uint8_t btn4 = 22; // bottom right button

const uint8_t leftBL = 26; // left backlight (red)
const uint8_t rightBL = 3; // right backlight (red)

uint8_t leds[5] = {7, A3, A1, 8, 5};

bool menuActive = false; // main Menu ISR handler variable,
// becomes true when main menu is opened and false when menu's over

bool showDateActive = false; // interrupt for showing date on home screen.
// triggered by BTN1

bool btn2IntActive = false; // ISR handler for BTN2
bool btn4IntActive = false; // ISR handler for BTN4

bool splitActive = false; // ISR handler variable for recording splits in chronograph

bool dispMode = 1; // 0 for wakeToCheck, 1 for AOD

// list of programs in main menu 8 elements long with each element 5 bytes (4 bytes + line end)
// first program is "quit", gets called when mainMenu() quits from no activity. Returns to main() loop.
char mainPrograms[9][5] = {"quit", "Chro", "data", "Adju", "prty", "sens", "Race", "Flsh", "game"};
char daysOfTheWeek[7][4] = {"Sun", "Mon", "Tue", "Wed", "Thu", "Fri", "Sat"};

uint8_t numPrograms = sizeof(mainPrograms) / sizeof(mainPrograms[0]);

// RTC time variables
uint8_t seconds = 0;
uint8_t minutes = 0;
uint8_t hours = 12;
uint16_t year = 24;
uint8_t month = 12;

uint8_t day = 29;

uint8_t temp = 0;

/*
Main menu interrupt handler.
When ISR is invoked, it simply changes menuActive to true and goes right back to main().
ISR is kept as short as possible to maintain high clock accuracy. Simply,
Interrupt called -> menuActive becomes true -> main() detects menuActive == true and runs mainMenu() -> menuActive turns false again
*/
void menuInt() {
  menuActive = true;
}

void showDateInt() {
  showDateActive = true;
}

void btn2Int() {
  btn2IntActive = true;
}

void btn4Int() {
  btn4IntActive = true;
}

// ISR for recording splits in chronograph
void recordSplitInt() {
  splitActive = true;
}

uint8_t getDayOfWeek(uint16_t y, uint16_t m, uint16_t d) {
  return (d+=m<3?y--:y-2,23*m/9+d+4+y/4-y/100+y/400)%7;
}

/*
Sets the time.
returns 0 in case of an error (hours > 23 or minutes > 59) but this shouldn't happen.
bool ampm is 0 for AM, 1 for PM
Automagically detects 12H/24H format and if user inputs in 12H format, asks for AM/PM as well
*/
bool setTime() {
  uint8_t hourTens = 0; // hour tens digit
  uint8_t hourOnes = 0; // hour ones digit
  uint8_t minuteTens = 0; // minute tens digit
  uint8_t minuteOnes = 0; // minute ones digit
  bool ampm = 0; // 0 for AM, 1 for PM
  TM8.dispStr("hour", 1); // indicate hour set mode
  uint32_t currentTime = millis();
  while(readBtn3 && millis() - currentTime <= 3000) { // until btn4 is pressed
    TM8.dispDec(hourTens * 10 + hourOnes, 0); // display hour value to set
    if (!readBtn1) { // btn1 increments tens digit
      hourTens++;
      if (hourTens > 2 || hourTens * 10 + hourOnes > 23) { // prevent overflow to stay within 0-23
        hourTens = 0;
      }
      currentTime = millis();
      delay(BUTTON_DELAY);
    }
    if (!readBtn2) { // btn2 increments ones digit
      hourOnes++;
      if (hourOnes > 9 || hourTens * 10 + hourOnes > 23) { // prevent overflow to stay within 0-23
        hourOnes = 0;
      }
      currentTime = millis();
      delay(BUTTON_DELAY);
    }
    if (!readBtn4) { // exit function for when triggered by mistake
      return 0;
    }
    if (millis() - currentTime > 3000) {
      return 0;
    }
  }
  TM8.dispStr("hour", 0); // confirm hour has been set
  TM8.dispStr(" set", 1);
  delay(750);
  TM8.dispStr(" min", 1); // indicate minute set mode
  while(readBtn3) { // until btn4 is pressed
    TM8.dispDec(minuteTens * 10 + minuteOnes, 0); // display minute value to set
    if (!readBtn1) { // btn1 increments tens digit
      minuteTens++;
      if (minuteTens > 5 || minuteTens * 10 + minuteOnes > 59) { // prevent overflow to stay within 0-59
        minuteTens = 0;
      }
      delay(BUTTON_DELAY);
    }
    if (!readBtn2) { // btn2 increments ones digit
      minuteOnes++;
      if (minuteOnes > 9 || minuteTens * 10 + minuteOnes > 59) { // prevent overflow to stay within 0-59
        minuteOnes = 0;
      }
      delay(BUTTON_DELAY);
    }
  }
  uint8_t hours = hourTens * 10 + hourOnes; // compute hour and minute values from selection
  uint8_t minutes = minuteTens * 10 + minuteOnes;
  if (hours > 23 || minutes > 59) { // error handling if hour/min values are beyond acceptable range, shouldn't happen tho
    TM8.dispStr(" Err", 0);
    TM8.dispStr("or  ", 1);
    delay(1000);
    return 0; // quit setTime()
  }
  // for some reason, doesn't work properly without the next three lines
  TM8.dispDec(hours, 0);
  TM8.dispDec(minutes, 1);
  delay(2000);
  if (hours > 12) { // if hour is set above 12, automatically set to PM
    ampm = 1;
  } else if (hours == 0) { // if hour is set to 0, automatically set to AM
    ampm = 0;
  } else if (hours <= 12) { // if hour is in 12H format(1-12), ask for AM/PM
    while(readBtn3) {
      if (ampm) {
        TM8.dispStr(" PM ", 0);
      } else {
        TM8.dispStr(" AM ", 0);
      }
      if (!readBtn1) { // btn1 sets time to AM
        ampm = 0; 
      }
      if (!readBtn2) { // btn2 sets to PM
        ampm = 1;
      }
    }
  }

  if (hours < 12 && ampm) { // if user input is 12H format and PM
    rtc.setHours(hours + 12); // set RTC to user input + 12 cuz RTC only understands 24H format
  } else if (hours == 12 && !ampm) { // if hour is set to 12 and AM
    rtc.setHours(0); // set RTC to 0 cuz RTC would take 12 as 12 PM
  } else {
    rtc.setHours(hours);
  }
  rtc.setMinutes(minutes);
  rtc.setSeconds(0);
  TM8.dispStr("time", 0);
  TM8.dispStr(" set", 1);
  delay(1000);
  for (int i=0; i<3; i++) {
    TM8.dispStr("", 0);
    TM8.dispStr("", 1);
    delay(50);
    TM8.dispStr("time", 0);
    TM8.dispStr("set", 1);
    delay(50);
  }
  return 1;
}

bool setDate() {
  uint8_t month = 12; // month value
  uint8_t dayTens = 2; // date tens digit
  uint8_t dayOnes = 9; // date ones digit
  TM8.dispStr("mnth", 1); // indicate month set mode
  while(readBtn3) { // until btn4 is pressed
    TM8.dispDec(month, 0); // display month value to set
    if (!readBtn1) { // btn1 increments month
      month++;
      if (month > 12 || month < 1) { // prevent overflow to stay within 1-12
        month = 1;
      }
      delay(BUTTON_DELAY);
    }
    if (!readBtn2) { // btn1 increments month
      month--;
      if (month > 12 || month < 1) { // prevent overflow to stay within 1-12
        month = 12;
      }
      delay(BUTTON_DELAY);
    }
    if (!readBtn4) { // exit function for when triggered by mistake
      return 0;
    }
  }
  TM8.dispStr("mnth", 0); // confirm month has been set
  TM8.dispStr(" set", 1);
  delay(750);
  TM8.dispStr(" day", 1); // indicate day set mode
  while(readBtn3) { // until btn4 is pressed
    TM8.dispDec(dayTens * 10 + dayOnes, 0); // display day value to set
    if (!readBtn1) { // btn1 increments tens digit
      dayTens++;
      if (dayTens > 3 || dayTens * 10 + dayOnes > 31) { // prevent overflow to stay within 0-31
        dayTens = 0;
      }
      delay(BUTTON_DELAY);
    }
    if (!readBtn2) { // btn2 increments ones digit
      dayOnes++;
      if (dayOnes > 9 || dayTens * 10 + dayOnes > 31) { // prevent overflow to stay within 0-31
        dayOnes = 0;
      }
      delay(BUTTON_DELAY);
    }
  }
  uint8_t date = dayTens * 10 + dayOnes;
  if (month > 12 || date > 31) { // error handling if hour/min values are beyond acceptable range, shouldn't happen tho
    TM8.dispStr(" Err", 0);
    TM8.dispStr("or  ", 1);
    delay(1000);
    return 0; // quit setTime()
  }
  // for some reason, doesn't work properly without the next three lines
  TM8.dispDec(month, 0);
  TM8.dispDec(date, 1);
  delay(2000);
  rtc.setDate(date, month, year);
  TM8.dispStr("date", 0);
  TM8.dispStr(" set", 1);
  delay(1000);
  for (int i=0; i<3; i++) {
    TM8.dispStr("", 0);
    TM8.dispStr("", 1);
    delay(50);
    TM8.dispStr("date", 0);
    TM8.dispStr("set", 1);
    delay(50);
  }
  return 1;
}

uint32_t chronoSplits[10]; // 10-long split record

/*
1/1000 second chronograph. Measures up to 59"59'999.
BTN4: start/stop chronograph
BTN3: record split. stops after all 10 slots are filled. record slot shown on rightmost digit.
BTN1: show time. Frequent use hampers precision.
Not using any interrupts to record splits cuz that caused problems where it would immediately record an interrupt
right when the chrono started. same for race chrono.
*/
bool chronoGraph() {
  uint8_t chronoSplitsCounter = 0;
  while(readBtn3) { // start when button 3 is pressed
    TM8.dispStr("btn3", 0);
    TM8.dispStr("strt", 1);
    if (!readBtn4) { // press btn4 to quit
      return 0;
    }
  } while(!readBtn3); // start on rising edge to prevent split recording immediately
  uint32_t chronoStartTime = millis(); // time when chronograph started, in milliseconds
  uint32_t chronoMillis; // declare variable for elapsed time in milliseconds
  uint32_t chronoSeconds; // ...elapsed time in seconds
  uint32_t chronoMinutes; // ...elapsed time in minutes
  while(readBtn4) { // until button 4 is pressed (btn4 will quit chronograph)
    chronoMillis = millis() - chronoStartTime; // compute elapsed time in milliseconds
    chronoSeconds = chronoMillis / 1000; // compute elapsed time in seconds
    chronoMinutes = chronoSeconds / 60; // compute elapsed time in minutes
    chronoMillis %= 1000; // compute elapsed milliseconds
    chronoSeconds %= 60; // compute elapsed seconds
    chronoMinutes %= 60; // compute elapsed minutes
    TM8.dispDec(chronoMinutes * 100 + chronoSeconds, 0); // display elapsed time on LCD
    TM8.dispDec(chronoMillis * 10 + chronoSplitsCounter, 1); // display elapsed milliseconds + split record slot on the right
    if (!readBtn3 && chronoSplitsCounter < 10) { // if button 3 is pressed and split record space is available
      while(!readBtn3) {digitalWrite(leds[5], 1);} // show split time & light up LED5 while btn3 is depressed
      digitalWrite(leds[5], 0); // turn off LED5
      TM8.dispDec(chronoMinutes * 100 + chronoSeconds, 0); // display split time
      TM8.dispDec(chronoMillis * 10 + chronoSplitsCounter, 1);
      chronoSplits[chronoSplitsCounter] = chronoMinutes * 100000 + chronoSeconds * 1000 + chronoMillis;
      Serial.print(chronoSplits[chronoSplitsCounter]); // debug messages
      Serial.println(chronoSplitsCounter);
      chronoSplitsCounter++; // increment chronoSplitsCounter
    }
    if (!readBtn1) { // if btn1 is pressed
      while(!readBtn1) {
        TM8.dispDec(rtc.getHours() * 100 + rtc.getMinutes(), 0); // display current time
        TM8.dispDec(rtc.getSeconds(), 1);
      }
    }
    // if (!readBtn4) {
    //   uint32_t millisBuffer = millis();
    //   TM8.dispDec(chronoMinutes * 100 + chronoSeconds, 0); // display stopped chrono time
    //   TM8.dispDec(chronoMillis * 10 + chronoSplitsCounter, 1);
    //   while(readBtn4) {};
    //   chronoStartTime = chronoStartTime - millisBuffer;
    // }
  }
  // quit chronograph animation
  delay(1000);
  TM8.dispStr("quit", 0);
  TM8.dispStr("chro", 1);
  delay(1000);
  for (int i=0; i<3; i++) {
    TM8.dispStr("quit", 0);
    TM8.dispStr("chro", 1);
    delay(75);
    TM8.dispStr("", 0);
    TM8.dispStr("", 1);
    delay(75);
  }
  return 0;
}

char tracks[12][5] = {
  "spa",
  "mnza",
  "nurb",
  "mnco",
  "szka"
};

float distances[12] {4.352, 3.600, 12.944, 2.074, 3.608};

uint32_t raceSplits[100] = {};
uint16_t averageSpeeds[100] = {};
uint8_t trackSelection = 0;

/*
Race chronograph. In addition to all features in the regular chronograph,
also shows average speed per split.
Can only measure up to 9"59.999
100-deep split record
*/
bool raceChrono() {
  uint8_t raceSplitsCounter = 0;
  while (readBtn3) {
    TM8.dispStr("trck", 0);
    TM8.dispStr(tracks[trackSelection], 1);
    if (!readBtn2) {
      trackSelection--;
      if (trackSelection > 4) trackSelection = 4;
      delay(BUTTON_DELAY);
    }
    else if (!readBtn1) {
      trackSelection++;
      if (trackSelection > 4) trackSelection = 0;
      delay(BUTTON_DELAY);
    }
  } while(!readBtn3); // start on rising edge to prevent split recording immediately
  delay(BUTTON_DELAY);
  while(readBtn3) { // start when button 3 is pressed
    TM8.dispStr("btn3", 0);
    TM8.dispStr("strt", 1);
    if (!readBtn4) { // press btn4 to quit
      return 0;
    }
  } while(!readBtn3); // start on rising edge to prevent split recording immediately
  uint32_t raceStartTime = millis(); // time when chronograph started, in milliseconds
  uint32_t raceMillis; // declare variable for elapsed time in milliseconds
  uint32_t raceSeconds; // ...elapsed time in seconds
  uint32_t raceMinutes; // ...elapsed time in minutes
  while(readBtn4) { // until button 4 is pressed (btn4 will quit chronograph)
    raceMillis = millis() - raceStartTime; // compute elapsed time in milliseconds
    raceSeconds = raceMillis / 1000; // compute elapsed time in seconds
    raceMinutes = raceSeconds / 60; // compute elapsed time in minutes
    raceMillis %= 1000; // compute elapsed milliseconds
    raceSeconds %= 60; // compute elapsed seconds
    raceMinutes %= 60; // compute elapsed minutes
    TM8.dispDec(raceMinutes * 100 + raceSeconds, 0); // display elapsed time on LCD
    TM8.dispDec(raceMillis * 10 + raceSplitsCounter, 1); // display elapsed milliseconds + split record slot on the right
    if (!readBtn3 && raceSplitsCounter < 100) { // if button 3 is pressed and split record space is available.
      while(!readBtn3) {
        digitalWrite(leds[5], 1); // show split time & light up LED5 while btn3 is depressed
        TM8.dispDec(raceMinutes * 100 + raceSeconds, 0); // display split time
        TM8.dispDec(raceMillis, 1);
      }
      digitalWrite(leds[5], 0); // turn off LED5
      float vavg = (distances[trackSelection]) / (float)((float)(millis() - raceStartTime) / 1000 / 3600);
      TM8.dispDec((int)(vavg), 0);
      TM8.dispDec(((vavg - (int)(vavg)) * 100), 1);
      raceSplits[raceSplitsCounter] = raceMinutes * 100000 + raceSeconds * 1000 + raceMillis;
      raceSplitsCounter++; // increment raceSplitsCounter
      delay(2000);
    }
    if (!readBtn1) {
      while(!readBtn1) {
        TM8.dispDec(rtc.getHours() * 100 + rtc.getMinutes(), 0);
        TM8.dispDec(raceSplitsCounter, 1);
      }
    }
  }
  // quit chronograph animation
  delay(1000);
  TM8.dispStr("quit", 0);
  TM8.dispStr("race", 1);
  delay(1000);
  for (int i=0; i<3; i++) {
    TM8.dispStr("quit", 0);
    TM8.dispStr("race", 1);
    delay(75);
    TM8.dispStr("", 0);
    TM8.dispStr("", 1);
    delay(75);
  }
  return 0;
}

/*
retrieves chronograph split records
first prompts whether to retrieve records from chrono or race
user selects btn1 for chrono, btn3 for race
*/
uint8_t chronoData() {
  TM8.dispStr("chro", 0); // prompt choice
  TM8.dispStr("race", 1);
  uint8_t chronoCounter = 0;
  uint8_t raceCounter = 0;
  while (readBtn1 && readBtn3); // wait for either btn1 or btn3 input
  if (!readBtn1) { // if chrono records selected
    delay(BUTTON_DELAY);
    while(readBtn4) {
      TM8.dispDec(chronoSplits[chronoCounter] / 1000, 0);
      TM8.dispDec((chronoSplits[chronoCounter] % 1000) * 10 + chronoCounter, 1);
      if (!readBtn1) {
        chronoCounter++;
        if (chronoCounter > 9) {
          chronoCounter = 0;
        }
        Serial.print(chronoSplits[chronoCounter]);
        delay(BUTTON_DELAY);
      } else if (!readBtn2) {
        chronoCounter--;
        if (chronoCounter > 9) {
          chronoCounter = 9;
        }
        Serial.print(chronoSplits[chronoCounter]);
        delay(BUTTON_DELAY);
      }
    }
  } else if (!readBtn3) { // if race records selected
    delay(BUTTON_DELAY);
    while(readBtn4) {
      TM8.dispDec(raceSplits[raceCounter] / 100, 0);
      TM8.dispDec((raceSplits[raceCounter] % 100) * 100 + raceCounter, 1);
      if (!readBtn1) {
        raceCounter++;
        if (raceCounter > 99) {
          raceCounter = 0;
        }
        Serial.print(raceSplits[raceCounter]);
        delay(BUTTON_DELAY);
      } else if (!readBtn2) {
        raceCounter--;
        if (raceCounter > 99) {
          raceCounter = 99;
        }
        Serial.print(raceSplits[raceCounter]);
        delay(BUTTON_DELAY);
      }
    }
  }
  return 0;
}

/*
Party mode.
Watch flashes custom messages and LEDs
*/
uint8_t party() {
  uint8_t cnt = 0;
  while(readBtn3) {
    if (cnt) {
      delay(BUTTON_DELAY);
      TM8.dispStr("OVTA", 0);
      TM8.dispStr("TIME", 1);
    } else {
      delay(BUTTON_DELAY);
      TM8.dispStr("it*s", 0);
      TM8.dispStr(" lit", 1);
    }
    if (!readBtn4) {
      TM8.dispStr("", 0);
      TM8.dispStr("", 1);
      delay(5000);
      TM8.animTach();
    }
    if (!readBtn2) {
      cnt = !cnt;
    }
    if (!readBtn1) {
      delay(5000);
      for (int i=0; i<5; i++) {
        digitalWrite(leds[i], 1);
      }
      delay(5000);
      for (int i=0; i<5; i++) {
        digitalWrite(leds[i], 0);
      }
      return 0;
    }
  }
  return 0;
}

void matchNumbersGame() {
  uint8_t numbers = 0;
  uint8_t hits = 0;
  while (hits < 3) {
  uint8_t target = rand() % 10;  /* generate a number from 0 - 9 */
  uint32_t startTime = millis();
    while(readBtn3) {
      if (numbers > 9) {numbers = 0;}
      if (numbers == 0) {TM8.dispStr("0000", 0);}
      else {TM8.dispDec(numbers * 1111, 0);}
      if (target == 0) {TM8.dispStr("0000", 1);}
      else {TM8.dispDec(target * 1111, 1);}
      if (millis() - startTime >= 200) {
        numbers++;
        startTime = millis();
      }
    }
    if (numbers == target) {
      hits++;
      TM8.dispStr("HIT ", 0);
      TM8.dispDec(hits, 1);
      delay(1000);
      for (int i=0; i<5; i++) {
        TM8.dispStr("HIT ", 0);
        TM8.dispDec(hits, 1);
        delay(50);
        TM8.dispStr("", 0);
        TM8.dispStr("", 1);
        delay(50);
      }
    } else {
      for (int i=0; i<5; i++) {
        TM8.dispStr("MISS", 0);
        TM8.dispStr("MISS", 1);
        tone(9, 4000);
        delay(50);
        TM8.dispStr("", 0);
        TM8.dispStr("", 1);
        noTone(9);
        delay(50);
      }
    }
  }
}

void reactionTimingGame() {

}
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
void loop() {
  alwaysOnDisplay();
  //wakeToCheck();
}

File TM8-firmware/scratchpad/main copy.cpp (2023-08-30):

/*
  ____________  _________   __  ______   ________  _______   ________
 /_  __/  _/  |/  / ____/  /  |/  /   | / ____/ / / /  _/ | / / ____/
  / /  / // /|_/ / __/    / /|_/ / /| |/ /   / /_/ // //  |/ / __/   
 / / _/ // /  / / /___   / /  / / ___ / /___/ __  // // /|  / /___   
/_/ /___/_/  /_/_____/  /_/  /_/_/  |_\____/_/ /_/___/_/ |_/_____/
Time Machine Mk. 8 firmware
Eric Min 2023

*/

#include <Wire.h>
#include "wiring_private.h" // pinPeripheral() function
#include <cdm4101.h>
#include <Adafruit_ASFcore.h>
#include <RTCZero.h>
#include <math.h>

#define NUM_MENU_PROGRAMS 3

// redefine classes into shorter names for easier coding
TwoWire wire1(&sercom2, 4, 3); // set up SERCOMs for I2C

CDM4101 lcd;

RTCZero rtc;

Adafruit_MAX17048 batt;

ArduinoLowPowerClass lowpower;

Adafruit_LIS3DH accel = Adafruit_LIS3DH();

const uint8_t leftR = 26;
const uint8_t leftG = 31;
const uint8_t leftB = 28;
const uint8_t rightR = 25;
const uint8_t rightG = A5;
const uint8_t rightB = 27;

const uint8_t btn1 = 2; // top left button
const uint8_t btn2 = 38;
const uint8_t btn3 = 24;
const uint8_t btn4 = 21;

const uint8_t led1 = 7; // top left LED
const uint8_t led2 = A3; // top left LED
const uint8_t led3 = A1; // top left LED
const uint8_t led4 = 8; // top left LED
const uint8_t led5 = 5; // center LED

const uint8_t rot1 = 13; // rotary bit 1
const uint8_t rot2 = 10; // rotary bit 2
const uint8_t rot4 = 11; // rotary bit 3
const uint8_t rot8 = 12; // rotary bit 4

// set time for RTC
const uint16_t second = 50;
const uint16_t minute = 29;
const uint16_t hour = 12;

const uint8_t cooker[] = {13, 10, 11, 12}; // array for cooker knob

// animations
uint8_t tachInit[7] = {0x00, 0x04, 0x0C, 0x2C, 0x6C, 0x6D, 0x6F};
uint8_t swipeDown[10] = {0x40, 0x61, 0x71, 0x7B, 0x7F, 0x3F, 0x1E, 0x0E, 0x04, 0x00};
uint8_t swirl[6] = {0x40, 0x20, 0x08, 0x04, 0x02, 0x01};

// variables for interrupt callbacks
bool cookerActive = false;
bool fuelActive = false;
bool setTimeActive = false;

uint8_t menuProgramNumber = 0;

// animation mimicking tachometer start-up on vintage cars
void animTach() {
  for (int i=0; i<7; i++) {
    for (int d=0; d<4; d++) {
      lcd.Digits[d] = tachInit[i];
    }
    lcd.Update(0);
    lcd.Update(1);
    delay(80);
  }
  delay(200);
  for (int i=6; i>=0; i--) {
    for (int d=0; d<4; d++) {
      lcd.Digits[d] = tachInit[i];
    }
    lcd.Update(0);
    lcd.Update(1);
    delay(80);
  }
}

// swirl animation on digit 1
void animSwirl(uint8_t times, bool disp) {
  for (int i=0; i<times; i++) {
    for (int i=0; i<6; i++) {
      lcd.Digits[1] = swirl[i];
    }
    lcd.Update(disp);
    delay(30);
  }
}
// "swipe down" animatin
void animSwipeDown(bool disp) {
  for (int i=0; i<10; i++) {
    for (int d=0; d<4; d++) {
      lcd.Digits[d] = swipeDown[i];
    }
    lcd.Update(disp);
    delay(80);
  }
}

// take read 4 bits from cooker knob and convert it into integer from 0-15
uint8_t readCooker() {
  uint8_t rot1 = !digitalRead(13);
  uint8_t rot2 = !digitalRead(10);
  uint8_t rot4 = !digitalRead(11);
  uint8_t rot8 = !digitalRead(12);
  uint8_t cookerVal = rot1 * pow(2, 0) + rot2 * pow(2, 1) + rot4 * pow(2, 2) + rot8 * pow(2, 3);

  return cookerVal;
}

/*
INTERRUPT HANDLERS
-> when interrupt is called, the interrupt callback changes a boolean state variable
and immediately goes back to main loop. Then, an "actual" function handles whatever
the interrupt was called to do. Simply,

Interrupt triggered -> state variable goes from "true" to "false"
-> function does its thing -> back to normal
*/
void showCooker() {
  lcd.dispDec(readCooker(), 0);
}

void showFuel() {
  uint8_t batteryLevel = round(batt.cellPercent());
  if (batteryLevel >= 100) {
    batteryLevel = 99;
  }

  lcd.dispDec(rtc.getSeconds() * 100 + batteryLevel, 1);
  lcd.dispDec(rtc.getHours() * 100 + rtc.getMinutes(), 0);
  delay(500);
}

// interrupt-driven function that shows the cooker value on the left LCD
void cookerInt() {
  cookerActive = true;
}

// shows battery percentage on right LCD
void fuelInt() {
  fuelActive = true;
}

void setTimeInt() {
  setTimeActive = true;
}

void menuInt() {
  menuProgramNumber++;
}

// sets the time
void setTime() {
  uint8_t times[3];

  for (int i=0; i<3; i++) {
    lcd.dispStr("    ", 0);
    lcd.dispStr("    ", 1);
    while (digitalRead(btn1)) {
      showCooker();
    }
    if (!digitalRead(btn1)) {
      times[i] = readCooker();
      lcd.dispStr("set ", 0);
      lcd.dispDec(times[i], 1);
      delay(1000);
    }
  }

  while (digitalRead(btn1) && digitalRead(btn3) == 1) {
    lcd.dispStr("A--P", 1);
  }
  if (!digitalRead(btn1)) {
    lcd.dispStr(" A  ", 0);
  } else if (!digitalRead(btn3)) {
    lcd.dispStr("  P ", 0);
  }
  delay(1000);

  if (times[0] > 12 || times[1] > 5 || times[2] > 9) {
    lcd.dispStr("Err ", 0);
    lcd.dispStr("Err ", 1);
    delay(1000);
  } else {
    rtc.setHours(times[0]);
    rtc.setMinutes(times[1] * 10 + times[2]);
    rtc.setSeconds(0);
    lcd.dispStr("time", 0);
    lcd.dispStr(" set", 1);
  }
}

void blinkGo() {
  for (int i=0; i<5; i++) {
    lcd.dispStr("    ", 1);
    delay(30);
    for (int i=0; i<4; i++) {
      lcd.dispCharRaw(i, 0x54, 1);
    }
    delay(30);
  }
  lcd.dispStr(" GO ", 1);
}

// bootup animation
void bootUpSitRep() {
  animTach();

  uint8_t error;
  uint8_t address;

  for(address = 1; address < 127; address++ ) {
    Wire.beginTransmission(address);
    error = Wire.endTransmission();
    if (error == 0) {
      if (address == 0x36) {
        lcd.dispStr("Fuel", 0);
        blinkGo();
        delay(500);
      } else if (address == 0x38) {
        lcd.dispStr("LCDl", 0);
        blinkGo();
        delay(500);
      }
    }
    
  }


  for(address = 1; address < 127; address++ ) {
    wire1.beginTransmission(address);
    error = wire1.endTransmission();
    if (error == 0) {
      if (address == 0x18) {
        lcd.dispStr("Accl", 0);
        blinkGo();
        delay(500);
      } else if (address == 0x76) {
        lcd.dispStr("temp", 0);
        blinkGo();
        delay(500);
      } else if (address == 0x38) {
        lcd.dispStr("LCDr", 0);
        blinkGo();
        delay(500);
      }
    }
  }
  delay(750);
  lcd.dispStr("", 1);
  lcd.dispStr("All ", 0);
  delay(750);
  lcd.dispStr("Syst", 0);
  lcd.dispStr("ems", 1);
  delay(750);
  lcd.dispStr("", 1);
  for (int i=0; i<7; i++) {
    lcd.dispStr(" GO ", 0);
    delay(75);
    lcd.dispStr("", 0);
    delay(75);
  }
}

uint16_t stopWatch() {

  lcd.dispStr("Chro", 0);
  lcd.dispStr("Chro", 1);
  while (digitalRead(btn3) && digitalRead(btn4));
  if (!digitalRead(btn4)) {
    lcd.dispStr("end", 0);
    return 0;
  } else if (!digitalRead(btn3)) {
    lcd.dispStr("time", 0);
    return 145665;
  }
  delay(1000);
}

void mainMenu() {

}
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

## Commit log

2023-06-17 got TM8's accelerometer to work!
2023-06-26 added beeps
    [tm8_XP2.sch]
2023-07-29 added sobriety game
    [tm8_XP2.sch]
2023-08-30 updated with more stuff
    [TM8_EVO_Dad.sch, TM8_EVO_Mom.sch, dock.brd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]
2023-12-17 made firing anim idle limit to save power
    [TM8_EVO_Dad.sch]
2023-12-17 split code more into two, LEDs don't work for some reason
2023-12-22 Integrated mouse jiggler and lock screen shortcut into one app
    [main.cpp]
2024-06-23 FW 1.8.3, added live temp reading and no seconds for longer battery life

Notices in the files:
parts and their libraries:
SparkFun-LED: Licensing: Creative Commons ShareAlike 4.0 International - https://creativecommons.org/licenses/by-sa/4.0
